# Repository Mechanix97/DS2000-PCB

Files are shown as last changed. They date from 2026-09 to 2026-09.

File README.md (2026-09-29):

<p align="center">
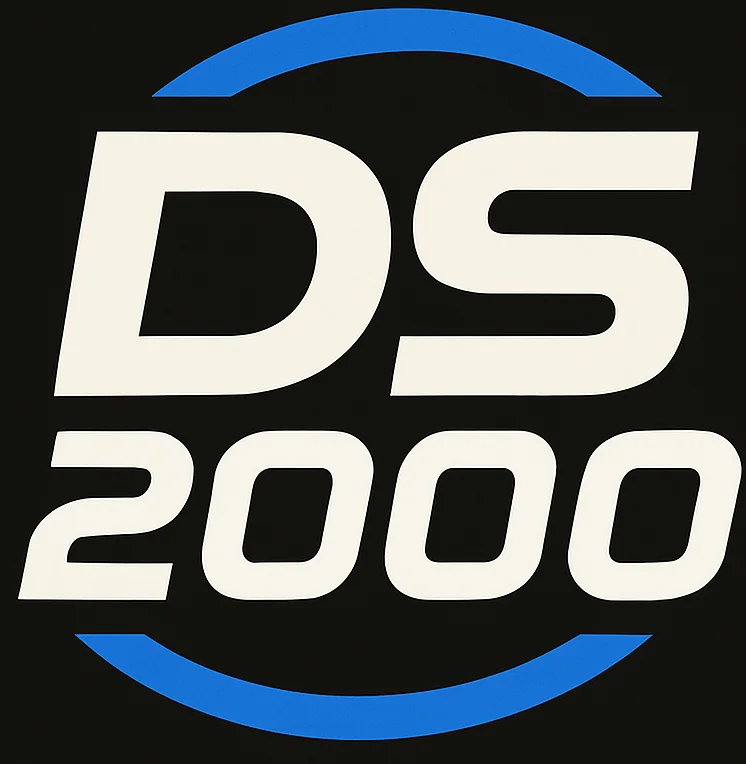
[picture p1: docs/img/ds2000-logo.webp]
DS2000
  
</p>

<p align="center">
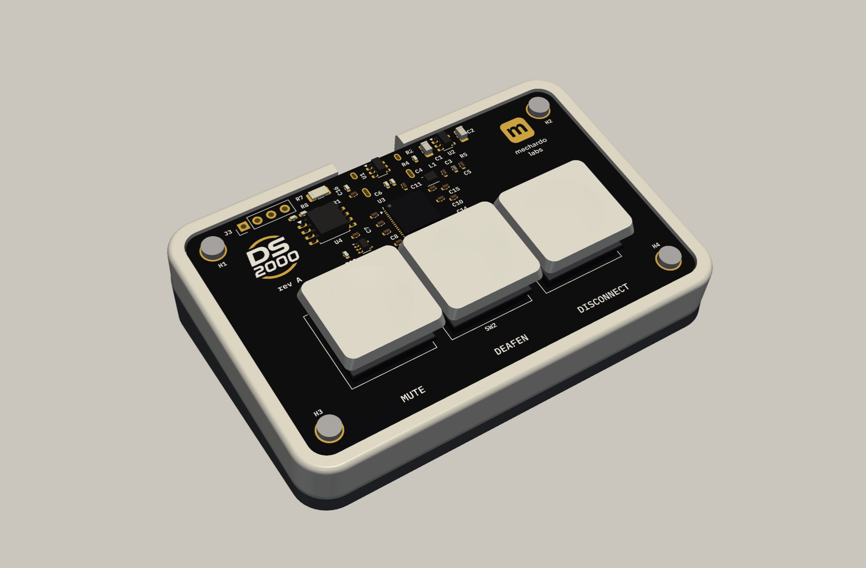
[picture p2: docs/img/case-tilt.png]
DS2000 rev A in its enclosure
  
</p>

<h1 align="center">DS2000 PCB</h1>

<p align="center">
  <b>Three keys for Discord: mute, deafen, disconnect.</b><br>
  RP2350A · Kailh Choc V1 · reverse-mounted RGB · USB-C · the board <i>is</i> the top face
</p>

KiCad design for the DS2000, a three-key Discord control deck. Mute and deafen are lit from
underneath by an RGB LED; disconnect has none. The board is also the device's visible top face: the
RP2350A, the logos and the legends are meant to be seen. It sits in a 3D-printed tray
([DS2000-Enclosure](https://github.com/Mechanix97/DS2000-Enclosure)).

| | |
|---|---|
| MCU | Raspberry Pi RP2350A |
| Keys | 3× Kailh Choc V1 (low profile) in a row, 18 mm pitch, soldered, MBK-style caps |
| LEDs | 2× SK6812MINI-E, reverse-mounted under the mute and deafen keys |
| Connector | USB-C (USB 2.0 full speed), or a cable soldered to J3 |
| Board | 4 layers, 1.6 mm, 72 × 46 mm, black mask, ENIG. RP2350A on show on top; USB-C, LEDs and debug pads underneath |
| Tool | **KiCad 10** |

Design decisions, block descriptions, BOM and open items: [`docs/design-rev-a.md`](docs/design-rev-a.md).

## In its enclosure

The same frame-style tray works flat on the desk or on a separate 7° wedge, held by magnets. The
board screws into it through its four corner holes.

<table>
  <tr>
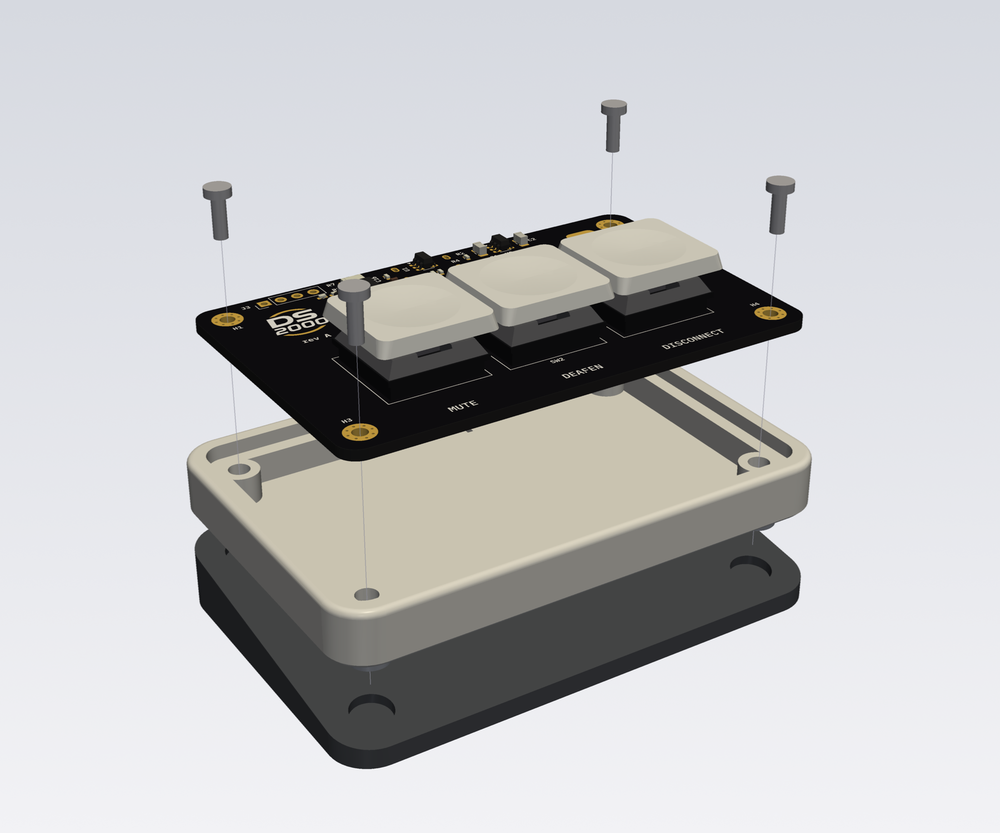
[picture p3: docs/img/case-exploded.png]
Exploded view: screws, board, tray, wedge
    <td width="50%"></td>
    <td width="50%">
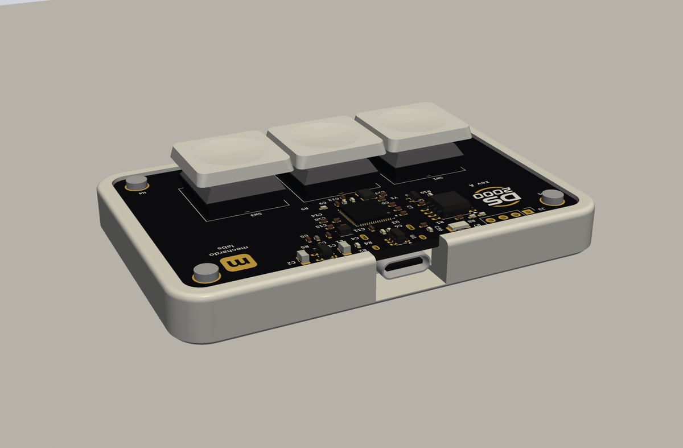
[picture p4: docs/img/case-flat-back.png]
Flat, from the back: USB-C through the frame
      <br>
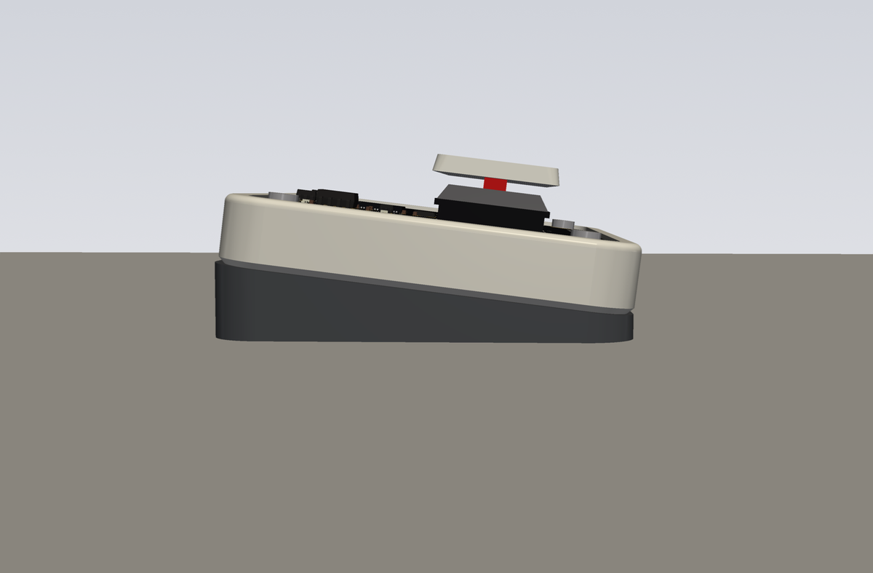
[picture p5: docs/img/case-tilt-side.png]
On the 7 degree wedge, from the side
      
    </td>
  </tr>
  <tr>
    <td>Exploded: four M2 screws, the board, the tray and the 7° wedge</td>
    <td>Flat, with the USB-C leaving straight back; and on the wedge, from the side</td>
  </tr>
</table>

## The board

| Top face, without switches | Underneath |
|---|---|
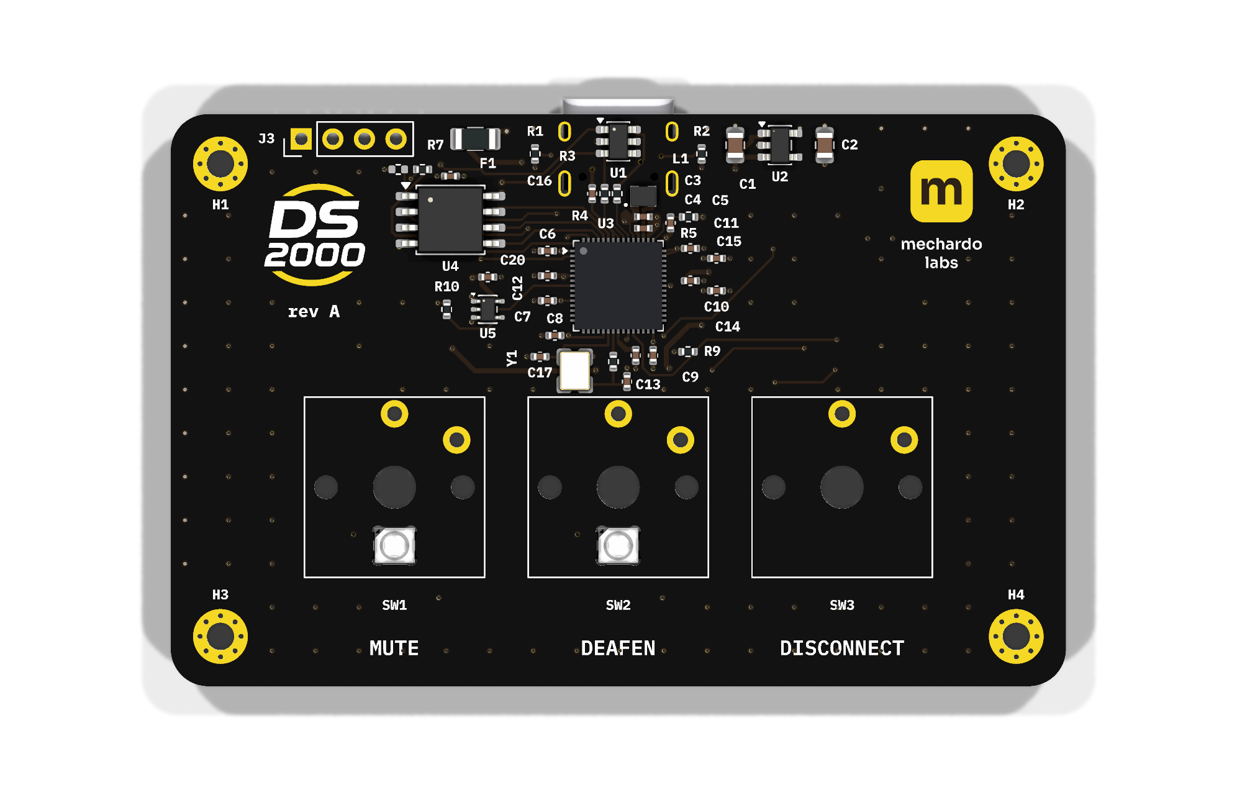
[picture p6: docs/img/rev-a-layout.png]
Top, without switches
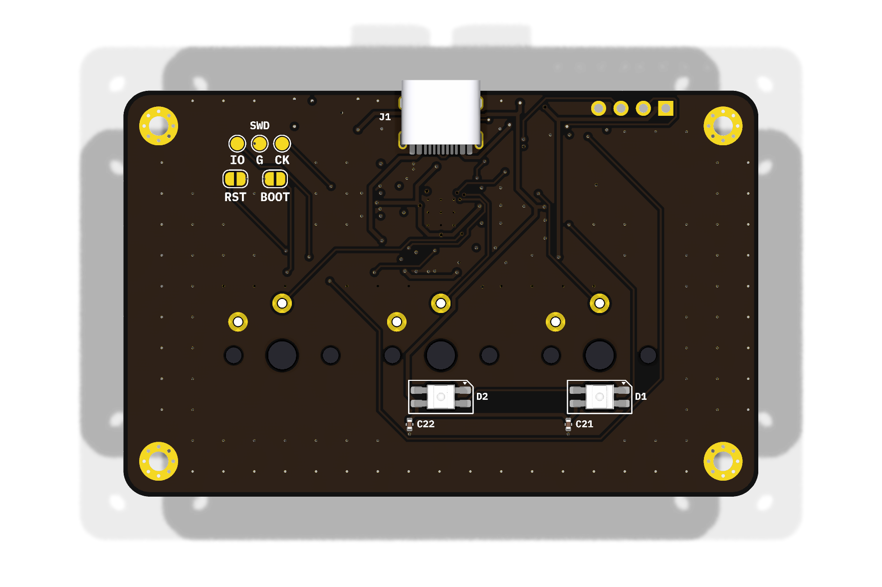
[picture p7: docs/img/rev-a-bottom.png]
Bottom
|  |  |
| The visible face: RP2350A, logos and legends | USB-C at the back edge, the two LEDs, debug pads (SWD, BOOT, RST) |

### Close up

| | |
|---|---|
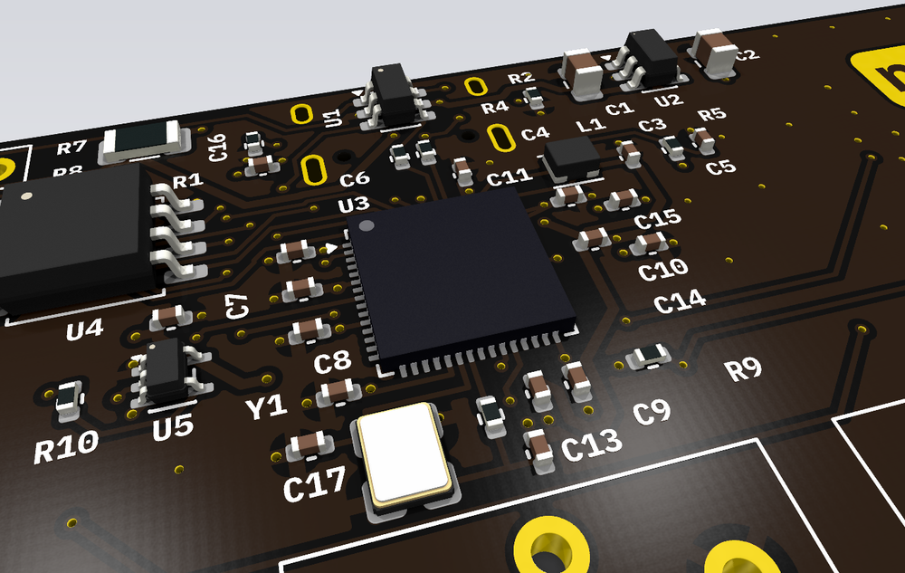
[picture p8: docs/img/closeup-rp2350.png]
RP2350A and its support parts
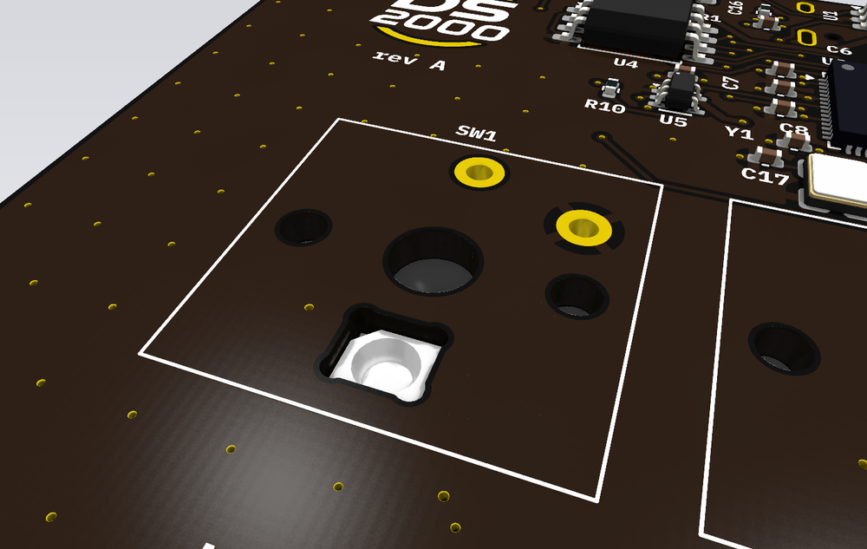
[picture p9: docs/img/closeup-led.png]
LED under the Choc switch
|  |  |
| **RP2350A on show**, with the flash, the 12 MHz crystal and the core regulator around it | **Light through the switch**: the SK6812MINI-E is mounted from below and shines through the Choc's LED window |
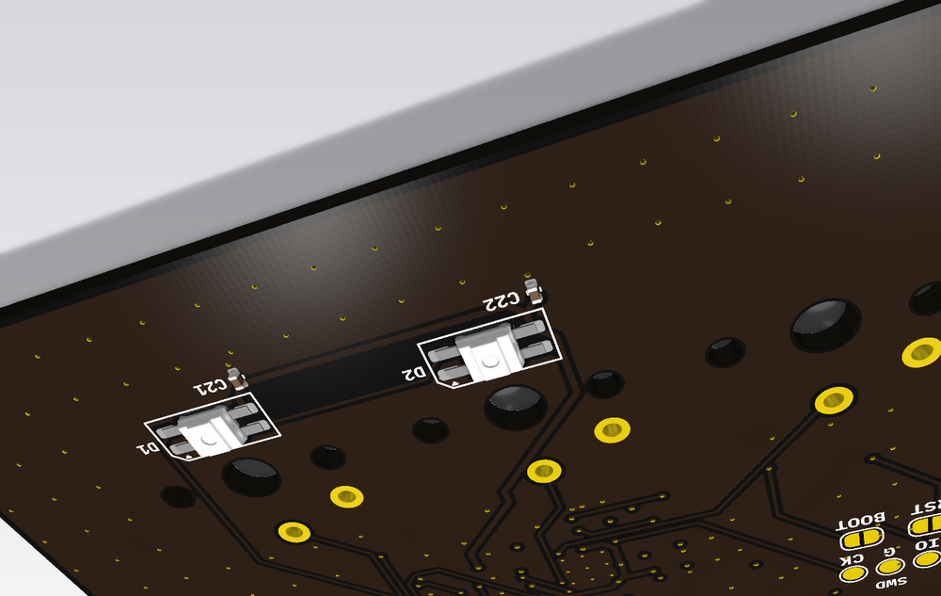
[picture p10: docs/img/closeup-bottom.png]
LEDs from below
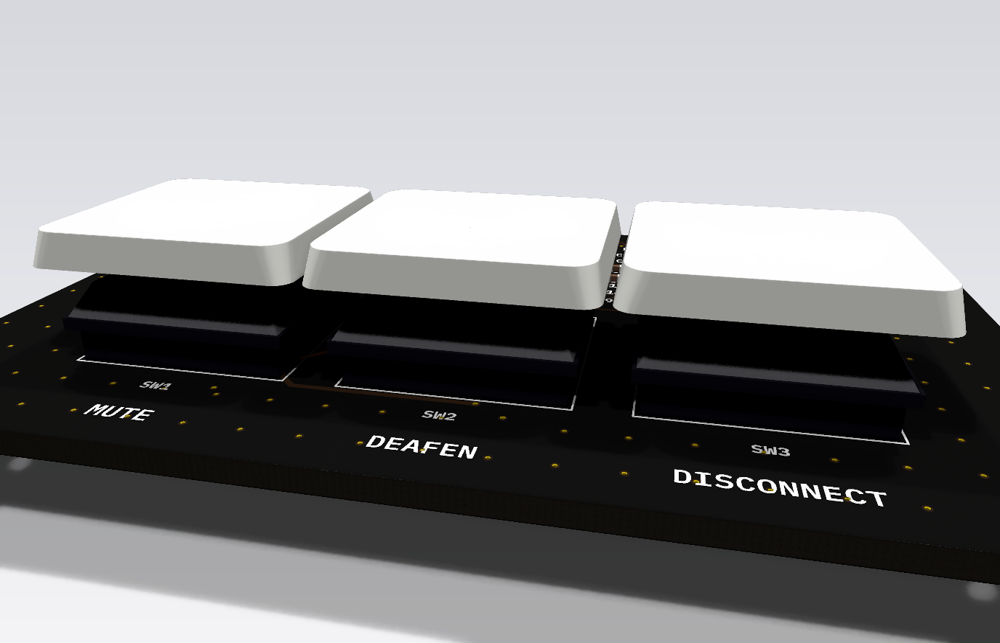
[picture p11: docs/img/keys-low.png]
Low-profile keys
|  |  |
| **Underneath**: both LEDs in a chain, each with its own 100 nF, and the debug pads | **Low profile**: Choc V1 with flat caps, keycap tops ~8.7 mm above the board |

<details>
<summary>More views</summary>

| With switches and keycaps | From the back |
|---|---|
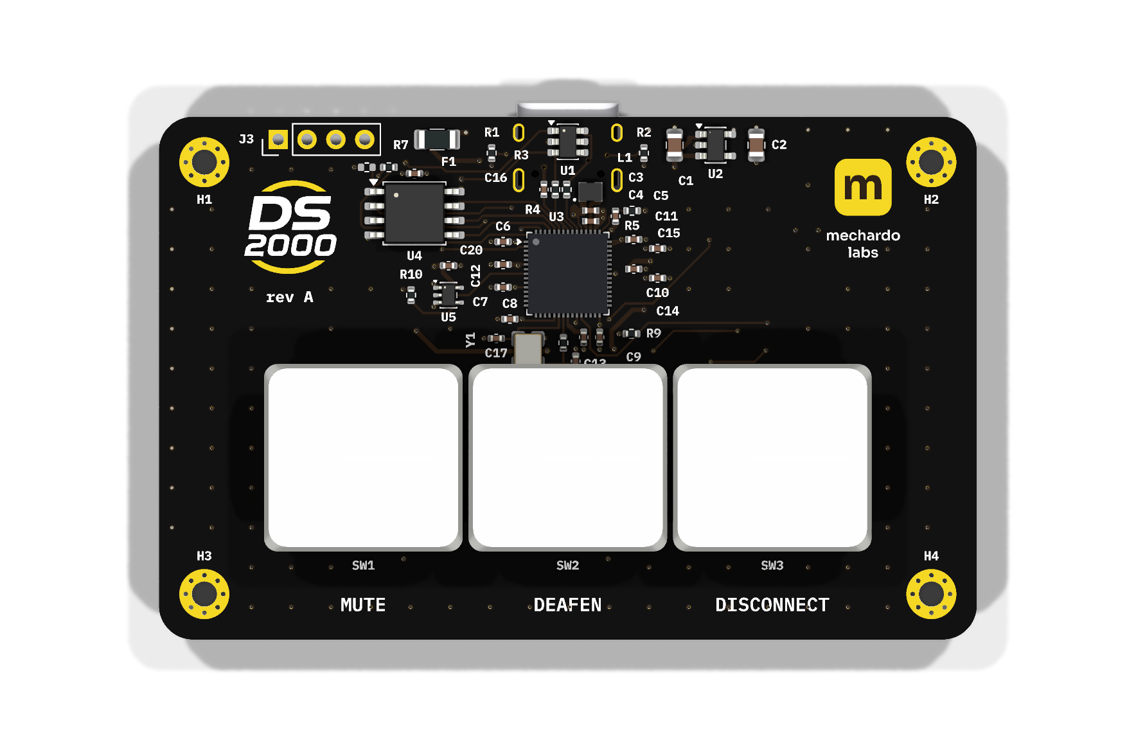
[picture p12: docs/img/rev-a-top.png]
Top
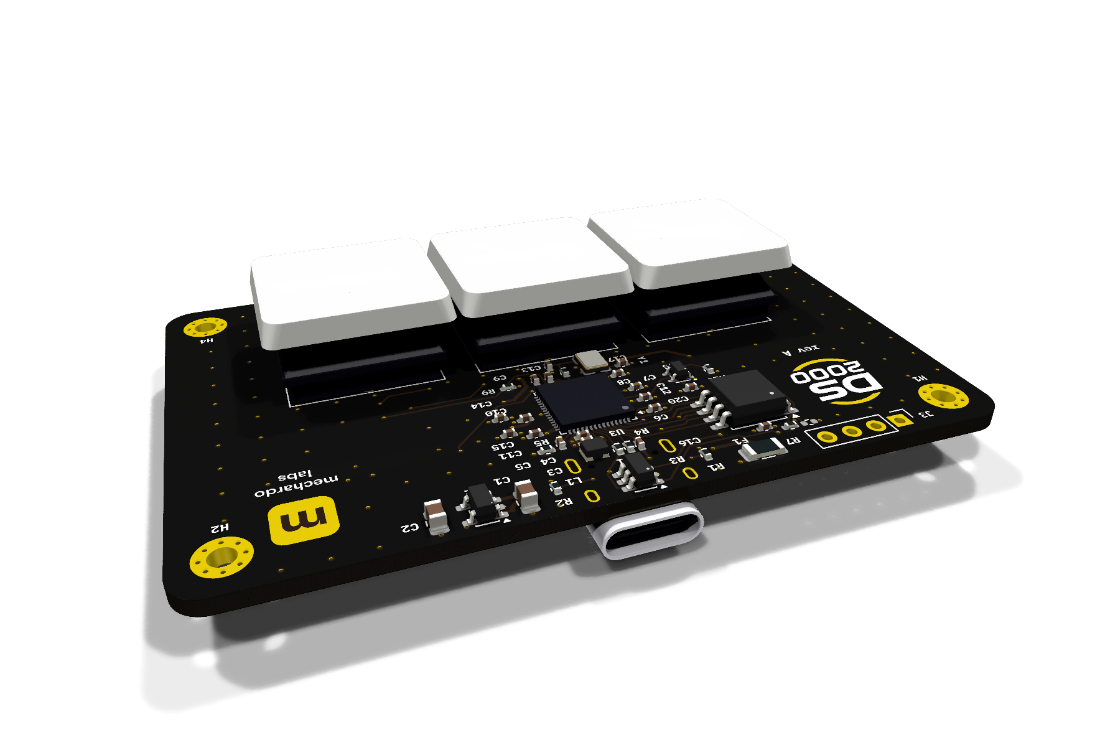
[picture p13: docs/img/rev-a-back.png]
Back
|  |  |

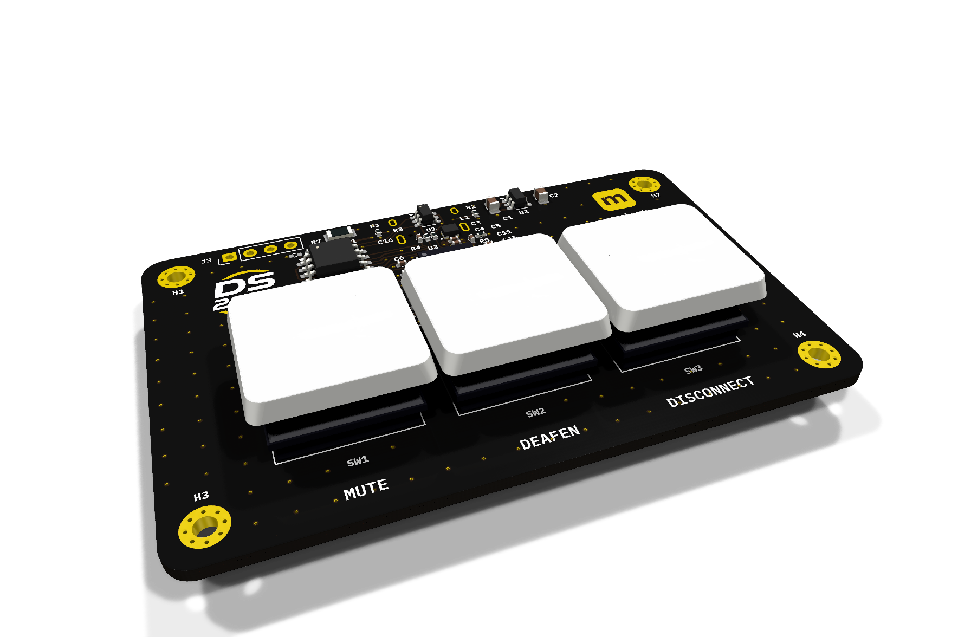
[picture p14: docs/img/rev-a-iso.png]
Isometric

</details>

### Schematic

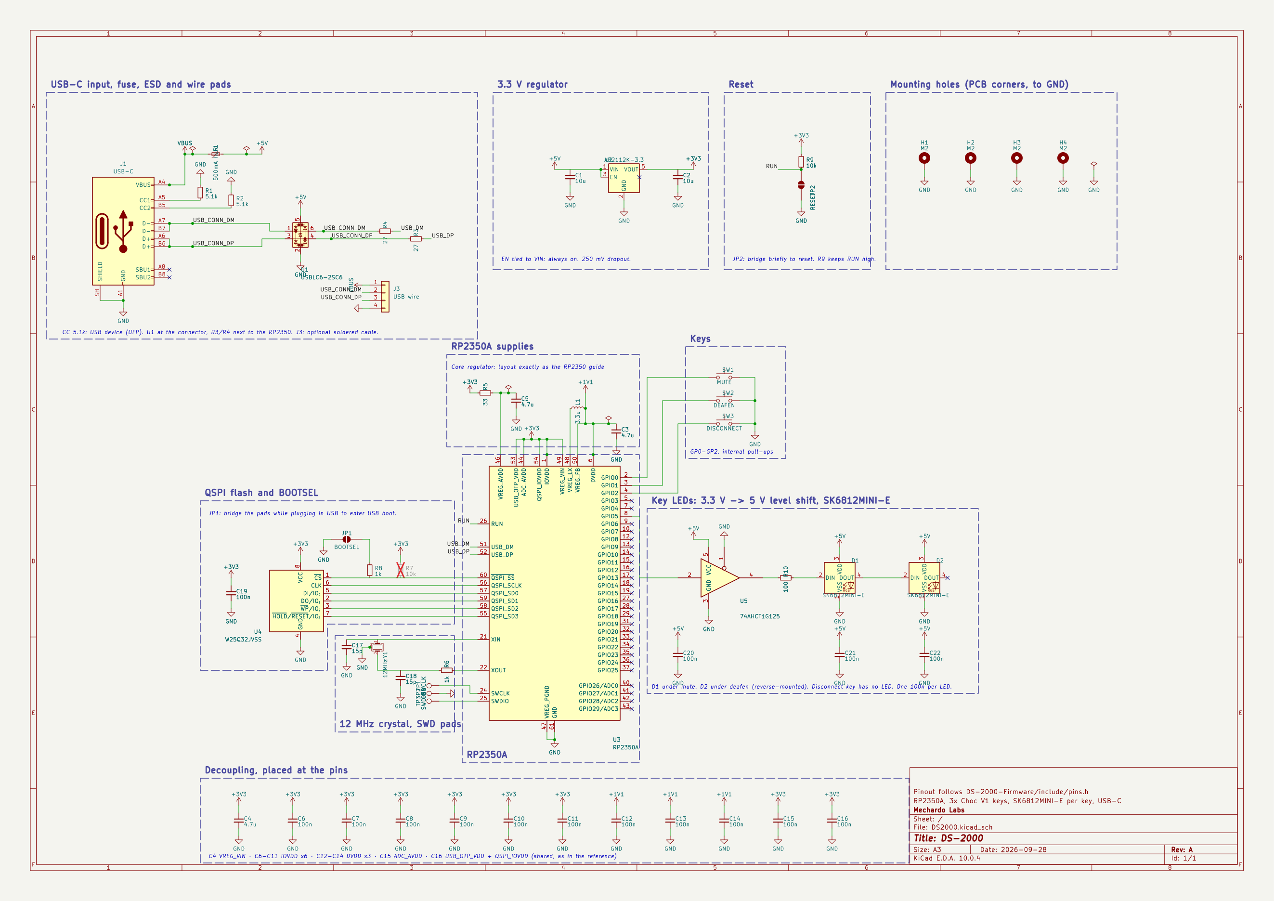
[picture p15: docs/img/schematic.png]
Schematic


One sheet, one box per block: USB-C input, 3.3 V regulator, RP2350A supplies, QSPI flash, crystal
and SWD, keys, and the LED chain with its 5 V level shifter.

## Pinout

The pinout is defined by the firmware (`DS2000-Firmware/include/pins.h`). Change it there first.

| Function | GPIO |
|---|---|
| Mute key | GP0 |
| Deafen key | GP1 |
| Disconnect key | GP2 |
| LED data (SK6812 chain, via 5 V level shifter) | GP5 |

## Checks

```sh
kicad-cli sch erc --severity-all DS2000.kicad_sch
kicad-cli sch export netlist --format kicadsexpr -o /tmp/ds2000.net DS2000.kicad_sch
```

CI (KiBot) runs ERC and DRC with schematic parity on every change and fails on any new error.

## Manufacturing

Every change also builds the files to order the board from JLCPCB, with assembly (artifact
`kibot-out` of the KiBot workflow):

- `JLCPCB/`: gerbers and drill (zipped), BOM with LCSC numbers, placement (CPL) with JLC's rotation fixes
- `step/`: the populated board as STEP, origin at its centre, for the [enclosure](https://github.com/Mechanix97/DS2000-Enclosure)

Board options, parts and what to check before ordering: [`docs/design-rev-a.md`](docs/design-rev-a.md#bill-of-materials).

## Related repositories

- [DS2000](https://github.com/Mechanix97/DS2000): desktop application
- [DS2000-Firmware](https://github.com/Mechanix97/DS2000-Firmware): firmware
- [DS2000-Enclosure](https://github.com/Mechanix97/DS2000-Enclosure): enclosure (Fusion 360)

## License

AGPL-3.0, see [`LICENSE`](LICENSE). Whether the hardware should move to CERN-OHL-S is discussed
in #16.

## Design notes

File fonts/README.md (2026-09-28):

# Fonts

The board's silkscreen uses the typography of [mechardo3d.xyz](https://mechardo3d.xyz):

| Face | Used for |
|---|---|
| Sora Bold | "DS2000" |
| Sora SemiBold | "mechardo labs" |
| IBM Plex Mono SemiBold | key legends |
| IBM Plex Mono Bold | references, debug labels, "rev A" |

`DS2000.kicad_pcb` embeds them, so KiCad renders the board correctly without installing anything.
To **edit** those texts, install the files in this folder first.

`SoraSemiBold-Regular.ttf` is a static instance of the variable Sora font at weight 600, renamed to
the family "Sora SemiBold" so KiCad can pick it by name.

Both families are under the SIL Open Font License 1.1 (`OFL-*.txt`).

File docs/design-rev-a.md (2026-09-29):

# DS2000 rev A — design notes

Rev A replaces the 2025 RP2040 draft (last seen at commit `7db9552`). It was drawn from scratch,
using the draft only as a reference, and fixes every defect found in it (DS2000-PCB#2-#10).

## Product decisions

| Decision | Choice | Why |
|---|---|---|
| MCU | Discrete **RP2350A** (QFN-60) | Same family as the RP2350-Zero test module the firmware runs on |
| Look | **Exposed PCB as the top face**, enclosure is a tray underneath | The board is the product's face: logo, art, legends in silkscreen |
| Top side | Switches, and **the RP2350A and its circuitry on show** in a strip behind the keys | The visible chip is part of the look |
| Bottom side | The two reverse-mount LEDs, the **USB-C receptacle** and **all debug pads** (SWD, BOOT, RST) | The plug and cable sit low, level with the tray, the top strip gains space, and debug stays off the visible face. Assembly is two-sided |
| Layers | 4 (Sig / GND / PWR / Sig), 1.6 mm | Routes mostly on inner layers so the face stays clean, solid reference for USB and the core regulator, stiff enough to hold switches without a plate |
| Finish (proposed) | Matte black soldermask, ENIG | Gold for exposed logo copper and mounting rings |
| Keys | 3× Kailh Choc V1 (low profile), **soldered, no plate**, in a row, MBK-style keycaps | Changed from Cherry MX for a lower, flatter device. Choc V1 has two locating posts, so it sits steady without a plate |
| Size | 72 × 46 mm | 3 keys at the Choc 18 mm pitch plus corner M2 holes; the extra depth is the component strip behind the keys. Kept from the MX layout so the enclosure's numbers stay put |
| Status | **SK6812MINI-E** reverse-mount under the mute and deafen keys; **disconnect has no LED** | Lights the key through the switch LED window; needs shine-through or translucent keycaps |
| Pinout | Owned by `DS2000-Firmware/include/pins.h` | See below |

## Blocks

**USB-C and power.** HRO TYPE-C-31-M-12 on the **bottom** side at the back edge, pointing backwards, so the plug and cable sit low and the top strip stays free. The tray needs a pocket of at least 4 mm under the board and a cut-out in its back wall for the plug overmould (about 12.5 × 6.5 mm). J3 is four bare 2.54 mm holes (VBUS, D-, D+, GND) to solder a USB cable instead of fitting J1; it sits upstream of the fuse and ESD, so a soldered cable is protected the same way. 5.1 kΩ on CC1/CC2
(UFP). VBUS goes through F1 (500 mA hold PTC) to `+5V`, which feeds the LEDs and the level shifter.
USBLC6-2SC6 ESD on D+/D- close to the connector. AP2112K-3.3 LDO (250 mV dropout, 600 mA) makes
`+3V3`; the RP2350 minimal design uses an NCP1117, but its ~1.1 V dropout leaves little margin from
a 4.75 V VBUS after the fuse.

**RP2350A.** Straight from *Hardware design with RP2350* (Minimal design, R4):

- Core supply from the on-chip switching regulator: `VREG_LX` → L1 3.3 µH → `+1V1` (DVDD ×3 and
  `VREG_FB`), C3 4.7 µF output, C4 4.7 µF on `VREG_VIN`, `VREG_AVDD` through R5 33 Ω / C5 4.7 µF.
  **L1 must be the polarity-marked Abracon AOTA-B201610S3R3-101-T, placed in the orientation and
  layout the guide shows.** Raspberry Pi explicitly says other layouts are at your own risk.
- `VREG_PGND` to GND, routed as the guide describes (not to an arbitrary via).
- **Layout: a copy of Raspberry Pi's RPI-RP2350A-MINIMAL R4-S1 board** (KiCad files, MIT), see
  *Core regulator* under Layout.
- 100 nF per power pin: C6-C11 IOVDD, C12-C14 DVDD, C15 ADC_AVDD, C16 shared by USB_OTP_VDD and
  QSPI_IOVDD (as in the reference).
- Crystal ABM8-272-T3 12 MHz, 15 pF load caps, 1 kΩ on XOUT. Do not substitute.
- USB 27 Ω series resistors R3/R4 close to the chip; D+/D- as a 90 Ω differential pair over
  unbroken GND.
- Flash W25Q32JVSSIQ (4 MB, same size as the RP2350-Zero, so the firmware image is identical).
  R7 (10 kΩ CS pull-up) is DNP as in the reference.
- BOOTSEL: no button. JP1 is a pair of bare pads (open solder jumper) that pull `QSPI_SS` low through
  R8 1 kΩ when bridged with tweezers or a wire while USB is plugged in (or RESET pressed).
  RESET: likewise pads, JP2, from `RUN` to GND; R9 10 kΩ keeps `RUN` high. Firmware updates do not
  need either: the running firmware reboots itself into USB boot (DS2000-Firmware#14, #15; DS2000#35).
- SWD on three bare pads on the bottom, TP1-TP3 (SWCLK, GND, SWDIO, the Debug Probe order); no connector.

**Keys and LEDs.** SW1-SW3 to GPIO0-2 and GND; the firmware uses the internal pull-ups (not
affected by the RP2350-E9 erratum, which concerns pull-downs). The LED data line leaves GPIO5 at
3.3 V and is shifted to 5 V by U5 (74AHCT1G125, TTL-level input), then R10 100 Ω, then the chain
D1 (mute) → D2 (deafen); D2's DOUT is unused. Each LED has its own 100 nF. SK6812 data input needs
0.7 × VDD = 3.5 V at 5 V, which a 3.3 V GPIO does not guarantee; hence the shifter.

## Pinout

| Function | GPIO | Net |
|---|---|---|
| Mute key | GP0 | `KEY_MUTE` |
| Deafen key | GP1 | `KEY_DEAFEN` |
| Disconnect key | GP2 | `KEY_DISCONNECT` |
| LED data (to U5) | GP5 | `LED_DIN_3V3` |

**Firmware impact** (tracked in Mechanix97/DS2000-Firmware#13): the six PWM LED pins (GP5-GP10) are gone. The firmware needs a
WS2812/SK6812 driver on GP5 (arduino-pico ships `Adafruit_NeoPixel`-compatible PIO drivers), and
`pins.h` changes accordingly. The serial protocol does not change: it already carries a colour for
each of the two status LEDs, which map one-to-one onto D1 and D2.

## Bill of materials

The MPN, manufacturer and LCSC number of every assembled part live in the schematic's fields, written
by `tools/bom/set_fields.py` (the parts table is there, with where each number was checked). The same
script copies them onto the board's footprints so the schematic parity check stays clean. Change a
part there and re-run it.

| Refs | Value | MPN | LCSC | Footprint |
|---|---|---|---|---|
| U3 | RP2350A | RP2350A | C42411118 | QFN-60 7×7 mm, thermal vias |
| U4 | Flash 4 MB | W25Q32JVSSIQ | C179173 | SOIC-8 5.3 mm |
| Y1 | 12 MHz | ABM8-272-T3 | C20625731 | 3225 4-pin |
| L1 | 3.3 µH | AOTA-B201610S3R3-101-T | C42411119 | 2016, polarity dot on pad 1 = +1V1 |
| U2 | 3.3 V LDO | AP2112K-3.3TRG1 | C51118 | SOT-23-5 |
| U1 | USB ESD | USBLC6-2SC6 | C7519 | SOT-23-6 |
| U5 | Buffer, TTL in | 74AHCT1G125GW,125 | C12495 | SOT-353 |
| D1, D2 | RGB LED | SK6812MINI-E | C5149201 | reverse mount 3.2×2.8, **bottom** |
| J1 | USB-C 16P | HRO TYPE-C-31-M-12 | C165948 | **bottom** |
| F1 | PTC 500 mA hold, 15 V | Littelfuse 1206L050/15YR | C151162 | 1206 (the 6 V 1206L050YR leaves little margin on VBUS) |
| C1, C2 | 10 µF 25 V X5R | CL21A106KAYNNNE | C15850 | 0805 |
| C3-C5 | 4.7 µF X5R | GRM155R60J475ME47D | C82453 | 0402 (C3/C4 wide land), as the RP2350 reference |
| C6-C16, C19-C22 | 100 nF 16 V X7R | CL05B104KO5NNNC | C1525 | 0402 (C21/C22 bottom) |
| C17, C18 | 15 pF C0G | 0402CG150J500NT | C1548 | 0402 |
| R1, R2 | 5.1 kΩ 1 % | 0402WGF5101TCE | C25905 | 0402 |
| R3, R4 | 27 Ω 1 % | RC0402FR-0727RL | C138021 | 0402, as the reference |
| R5 | 33 Ω 1 % | RC0402FR-0733RL | C138002 | 0402, as the reference |
| R6, R8 | 1 kΩ 1 % | 0402WGF1001TCE | C11702 | 0402 |
| R7 | 10 kΩ, **DNP** | 0402WGF1002TCE | C25744 | 0402 |
| R9 | 10 kΩ 1 % | 0402WGF1002TCE | C25744 | 0402 |
| R10 | 100 Ω 1 % | 0402WGF1000TCE | C25076 | 0402 |
| SW1-SW3 | Keys | Kailh Choc V1 (CPG1350) | — | soldered by hand |
| TP1-TP3, JP1, JP2, J3, H1-H4 | pads, jumpers, wire holes, M2 holes | — | — | bare copper |

**Ordering from JLCPCB.** CI builds the files on every change (KiBot's JLCPCB template, artifact
`kibot-out`, folder `JLCPCB/`): gerbers and drill zipped, the BOM and the placement (CPL) file with
JLC's rotation corrections. Upload the zip as the PCB, then the BOM and CPL for assembly:

- 4 layers, 1.6 mm, **black** mask, white silk, **ENIG**, JLC04161H-7628 stackup
- assembly on **both sides**: D1, D2, C21, C22 and J1 are on the bottom
- JLC's BOM page shows which lines are basic or extended parts (extended ones add a setup fee each)
- check the placement preview, above all the rotation of U3, U5, D1/D2 and J1, before confirming
- the switches are fitted by hand after assembly

## Layout

rev A, routed

**State:** placed and fully routed. ERC is clean; DRC reports no unconnected pads, no clearance or
edge errors and full schematic parity (Update PCB from Schematic reports no changes). The only DRC
item left is the intended USB-C footprint change described under *Face and branding*.

**Fixed (mechanical, agreed with the enclosure):**

| Item | Position |
|---|---|
| Outline | 72 × 46 mm, 3 mm corner radius |
| Keys | row of 3 at 18 mm pitch, centres 16 mm from the front edge, middle key on the board's centre line |
| LEDs | D1/D2 on the bottom, 4.7 mm south of the switch centre (the Choc V1 LED window, opposite the switch pins), turned so DOUT faces the next LED |
| Holes | 4 × M2, 4 mm in from each edge, clear of the keycaps |
| USB-C | bottom side, centred on the back edge, face **1.2 mm past the edge** (its front shield tabs keep 0.6 mm of board), opening facing back |
| Debug | **all on the bottom**, back right: SWD pads TP1-TP3 (CK, G, IO), BOOT (JP1), RST (JP2) |
| USB wire holes (J3) | back edge, left |

**Top side, around the RP2350A:** flash top-left by the QSPI pins, core regulator straight above the
VREG pins, USB series resistors beside it above D+/D-, crystal below XIN/XOUT, each decoupling
capacitor in line with its supply pin and its supply pad facing it.

**Core regulator.** Raspberry Pi says their regulator layout should be copied, not improvised: the
inductor's field upsets the output capacitor when it is the wrong way round or placed differently.
Rev A copies it from their KiCad files (RPI-RP2350A-MINIMAL R4-S1, MIT). Our U3 sits the same way
round as theirs, so every offset from VREG_LX (pin 48) carries over unchanged:

| Theirs | Ours | Part | From pin 48 (x, y), mm |
|---|---|---|---|
| C6 | C4 | 4.7 µF, VREG_VIN | (0, −1.16) |
| C7 | C3 | 4.7 µF, +1V1 output | (0, −2.10) |
| L1 | L1 | AOTA-B201610S3R3-101-T, dot (pad 1) on +1V1, left | (0, −3.75) |
| C9 | C5 | 4.7 µF, VREG_AVDD | (2.2, −1.60) |
| R3 | R5 | 33 Ω, VREG_AVDD filter | (3.65, −2.08) *(theirs: (2.2, −3.45))* |
| C12 | C16 | 100 nF, USB_OTP_VDD + QSPI_IOVDD | (−4.1, −3.95) |
| R7/R8 | R3/R4 | 27 Ω, USB | (−3.1 / −2.1, −3.95) |

- The two 4.7 µF caps use the reference's wide 0402 land (`DS2000:C_0402_1005Metric_Wide`, pads
  1.03 mm apart) so VREG_LX runs straight up between them to L1.
- VREG_PGND (47) ties to both caps' ground pads on the top layer, with two vias beside them, as in
  the reference; VREG_FB (50) is taken at the output cap; VREG_AVDD runs clear of L1.
- The tracks are hand-placed by `preroute.py` and locked; `vreg_pours.py` adds the reference's four
  small pours (PGND, VREG_LX, the +1V1 node, VREG_VIN) after autorouting.
- The reference's +3V3 pour under the package (joining VREG_VIN to pins 53/54) becomes a track in the
  same place, between the pin ring and the exposed pad, with one via to the In2 plane.
- **Two departures**, both forced by J1 underneath: the whole RP2350A cluster sits 0.5 mm lower than
  first placed so L1 and C16 clear J1's plastic pegs, and R5 lies beside C5 instead of above it,
  where J1's shell pin comes through. R5 only feeds the 200 µA AVDD filter, away from L1's field.
- No via lands on J1's bottom-side contacts: every via on the board is at least 0.4 mm clear of them.

**Face and branding** (`tools/pcb-generator/branding.py`, safe to re-run on the hand-edited board):

- F.Cu carries a GND pour as well, so all four layers are ground or +3V3 wherever there is no track.
  Its thermal reliefs may resolve to a single spoke (`DS2000.kicad_dru`): every top GND pad already
  reaches In1 through its own via.
- Every reference designator is visible, placed by a script at the first spot beside its part that
  clears pads, holes, vias, other text and the board edge. The three that find no room (C6, C11, R3,
  in the tightest spot around the RP2350A) stay hidden; they are still in the assembly drawings.
- Typography follows mechardo3d.xyz: Sora for "DS2000" and "mechardo labs", IBM Plex Mono for the
  key legends, references and debug labels. The fonts are embedded in the board file; `fonts/` has
  them for editing. KiCad reports `text_thickness` on some characters (5, 6, 9, G, a, e): its check
  measures the thinnest part of each glyph, where curves taper. The main strokes of Plex Mono Bold at
  0.8 mm are about 0.16 mm, above JLC's 0.153 mm minimum.
- The DS2000 logo (back left) is the product logo from mechardo3d.xyz
  (`static/images/DS2000/logo/ds2000-logo.webp`), traced by `tools/logo/gen_ds2000_logo.py` into
  `DS2000.pretty/Logo_DS2000_8.6mm`: the white lettering is silkscreen, the blue arcs become ENIG
  gold, since the board has no blue. "rev A" sits under it; the maker block (Mechardo mark with
  "mechardo / labs") sits back right.
- The Mechardo Labs mark is the mechardo3d.xyz favicon (`tools/logo/gen_logo.py` →
  `DS2000.pretty/Logo_Mechardo_5mm`): a rounded square of ENIG copper whose mask opening leaves the
  "m" covered, so it reads black on gold. The SVG's "m" is a single self-overlapping contour, so it is
  first resolved to its nonzero-fill union; taken as-is the overlaps rendered as holes.
- The USB-C's own silkscreen, which fell past the board edge, is on the fab layer; that is the one
  intended `lib_footprint_mismatch` in the DRC output.

**How it was routed** (`tools/pcb-generator/`, see `pipeline.py`):

1. `gen_pcb.py` builds the board from the schematic's netlist (footprints, nets, fields, symbol
   links), places it, and sets stackup, rules and net classes.
2. `preroute.py` hand-routes what the autorouter should not improvise, as locked tracks: the crystal
   loop (XIN 7.4 mm, XOUT 2.1 mm, crystal output 4.9 mm, no vias, the crystal turned so the two
   nets never cross) and IOVDD pin 20, which runs to its capacitor above the XIN run.
3. `fanout.py` connects every GND and +3V3 pad to its plane: RP2350A supply pins go by a short
   track straight to their decoupling capacitor, pins 53/54 share one via between the USB and QSPI
   escapes, and every other pad gets its own via, each checked for clearance before it is placed.
4. Freerouting routes the rest on F.Cu and B.Cu (In1 and In2 are planes). The top is the product's
   face, so `top_keepout.py` first puts a track keepout on F.Cu over everything but the component
   strip around the RP2350A (x 80.5-119, y 71-93.6): the keys, the logos and the sides stay free of
   tracks and every longer run (+5V to the LEDs, the debug lines, the keys) goes underneath. The
   keepout comes out again after routing. Incremental passes are kept only when KiCad's own DRC
   counts fewer unconnected items, and `cleanup_vias.py` drops any via left dangling.
5. `branding.py` finishes the face (see above) and `stitch.py` ties the F.Cu and B.Cu GND pours to
   In1 with a 3.5 mm grid of vias wherever they clear everything else (113 on rev A).

`pipeline.py` writes to `build/` and never overwrites the committed board: from now on the
`.kicad_pcb` is edited by hand in KiCad.

**3D models:** KiCad's library has no STEP for the Choc V1 switch, the HRO USB-C or the QFN-60, so
`tools/3d-models/gen_models.py` generates simplified ones from datasheet dimensions into
`3dmodels/DS2000.3dshapes/` (referenced through `${KIPRJMOD}`, so they travel with the project). The
switches also carry an MBK-style keycap model for previews and for fitting the enclosure. The Cherry MX
models stay in the generator for reference.

**Choc V1 footprint:** `DS2000.pretty/SW_Kailh_Choc_V1_1.00u`, written by `tools/footprints/gen_choc_v1.py`
from Kailh's CPG1350 datasheet; the geometry matches kiswitch's footprint of the same name (MIT). Its
courtyard follows the 13.8 mm lower housing: the 15 mm flange is 2.2 mm up, so the crystal and C18
tuck under its edge.

**Stackup and rules:** JLCPCB JLC04161H-7628, 4 layers, 1.6 mm, black mask, white silk, ENIG.
In1 is the GND plane, In2 the +3V3 plane, F.Cu and B.Cu GND pours (solid joins on B.Cu). Minimums set for
JLC: 0.1 mm track and clearance, 0.2 mm drill, 0.3 mm copper to edge (0.2 mm only for the LED
cut-outs, in `DS2000.kicad_dru`). Net classes: *Plane* (GND, +3V3) reached by vias, *Power* (+5V,
+1V1, VBUS, VREG_LX) 0.4 mm, *USB* 0.2 mm tracks / 0.2 mm gap.

**Review (2026-09-28).** Every net was checked against Raspberry Pi's RP2350 minimal design and
every footprint's pin mapping against its datasheet, including the SK6812MINI-E: its datasheet
numbers pins differently from KiCad's symbol, but KiCad's reverse-mount footprint is drawn mirrored,
so once placed on the bottom each pad lands on the right function. No wrong connection was found.
The review did find routing the autorouter had done poorly, since fixed: XIN was 14 mm with two
vias and the QSPI clock 35.5 mm with four (now 7.4 mm with none, and 11 mm with two). The USB data
lines carry a ~2 cm stub to the J3 wire holes, which is harmless at full speed (12 Mbit/s).

**Review before ordering:**

- Core regulator: copied from the reference (see above). At assembly, check L1's dot sits on the
  left, towards +1V1 (the silkscreen dot marks it).
- USB: confirm the 90 Ω pair geometry with JLC's impedance calculator for this stackup.
- Under the keycaps (outside each switch's 13.8 mm lower housing) parts are hidden but must stay under
  ~2 mm high: the switch flange is 2.2 mm up and a pressed Choc keycap comes down close to it.
- Confirm the LED side against your switches: the footprint assumes the LED window is on the side
  opposite the two switch pins, as in Kailh's CPG1350 drawing.

## Open items

- [ ] Review the routed board (see Layout, *Review before ordering*)
- [ ] Mute and deafen keycaps must be shine-through or translucent for their LEDs to be visible

## Regenerating the schematic

`tools/schematic-generator/gen_sch.py` produced the first version of `DS2000.kicad_sch`: one titled
box per stage, wired inside each stage, net labels only between stages. `check_netlist.py` compares
KiCad's netlist export with the connectivity declared in the generator; both it and ERC (0
violations) passed. From here on,
**the `.kicad_sch` is the source of truth**: edit it in KiCad. The generator is kept only as a
record of how the first version was derived.

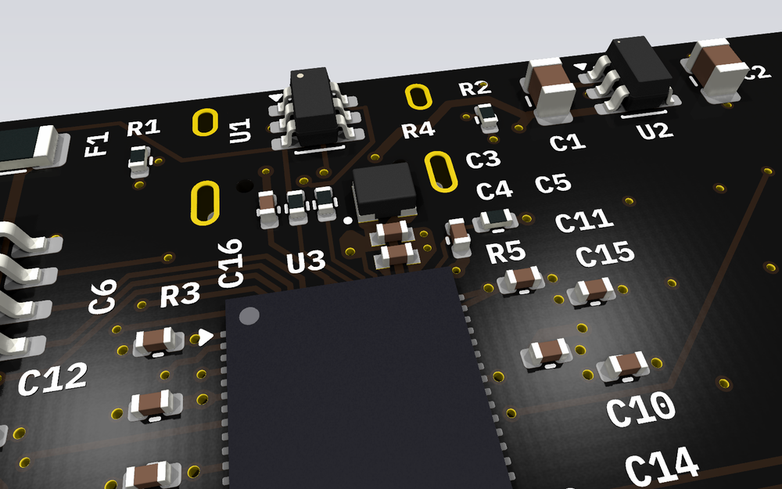
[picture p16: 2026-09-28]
docs/img/closeup-vreg.png

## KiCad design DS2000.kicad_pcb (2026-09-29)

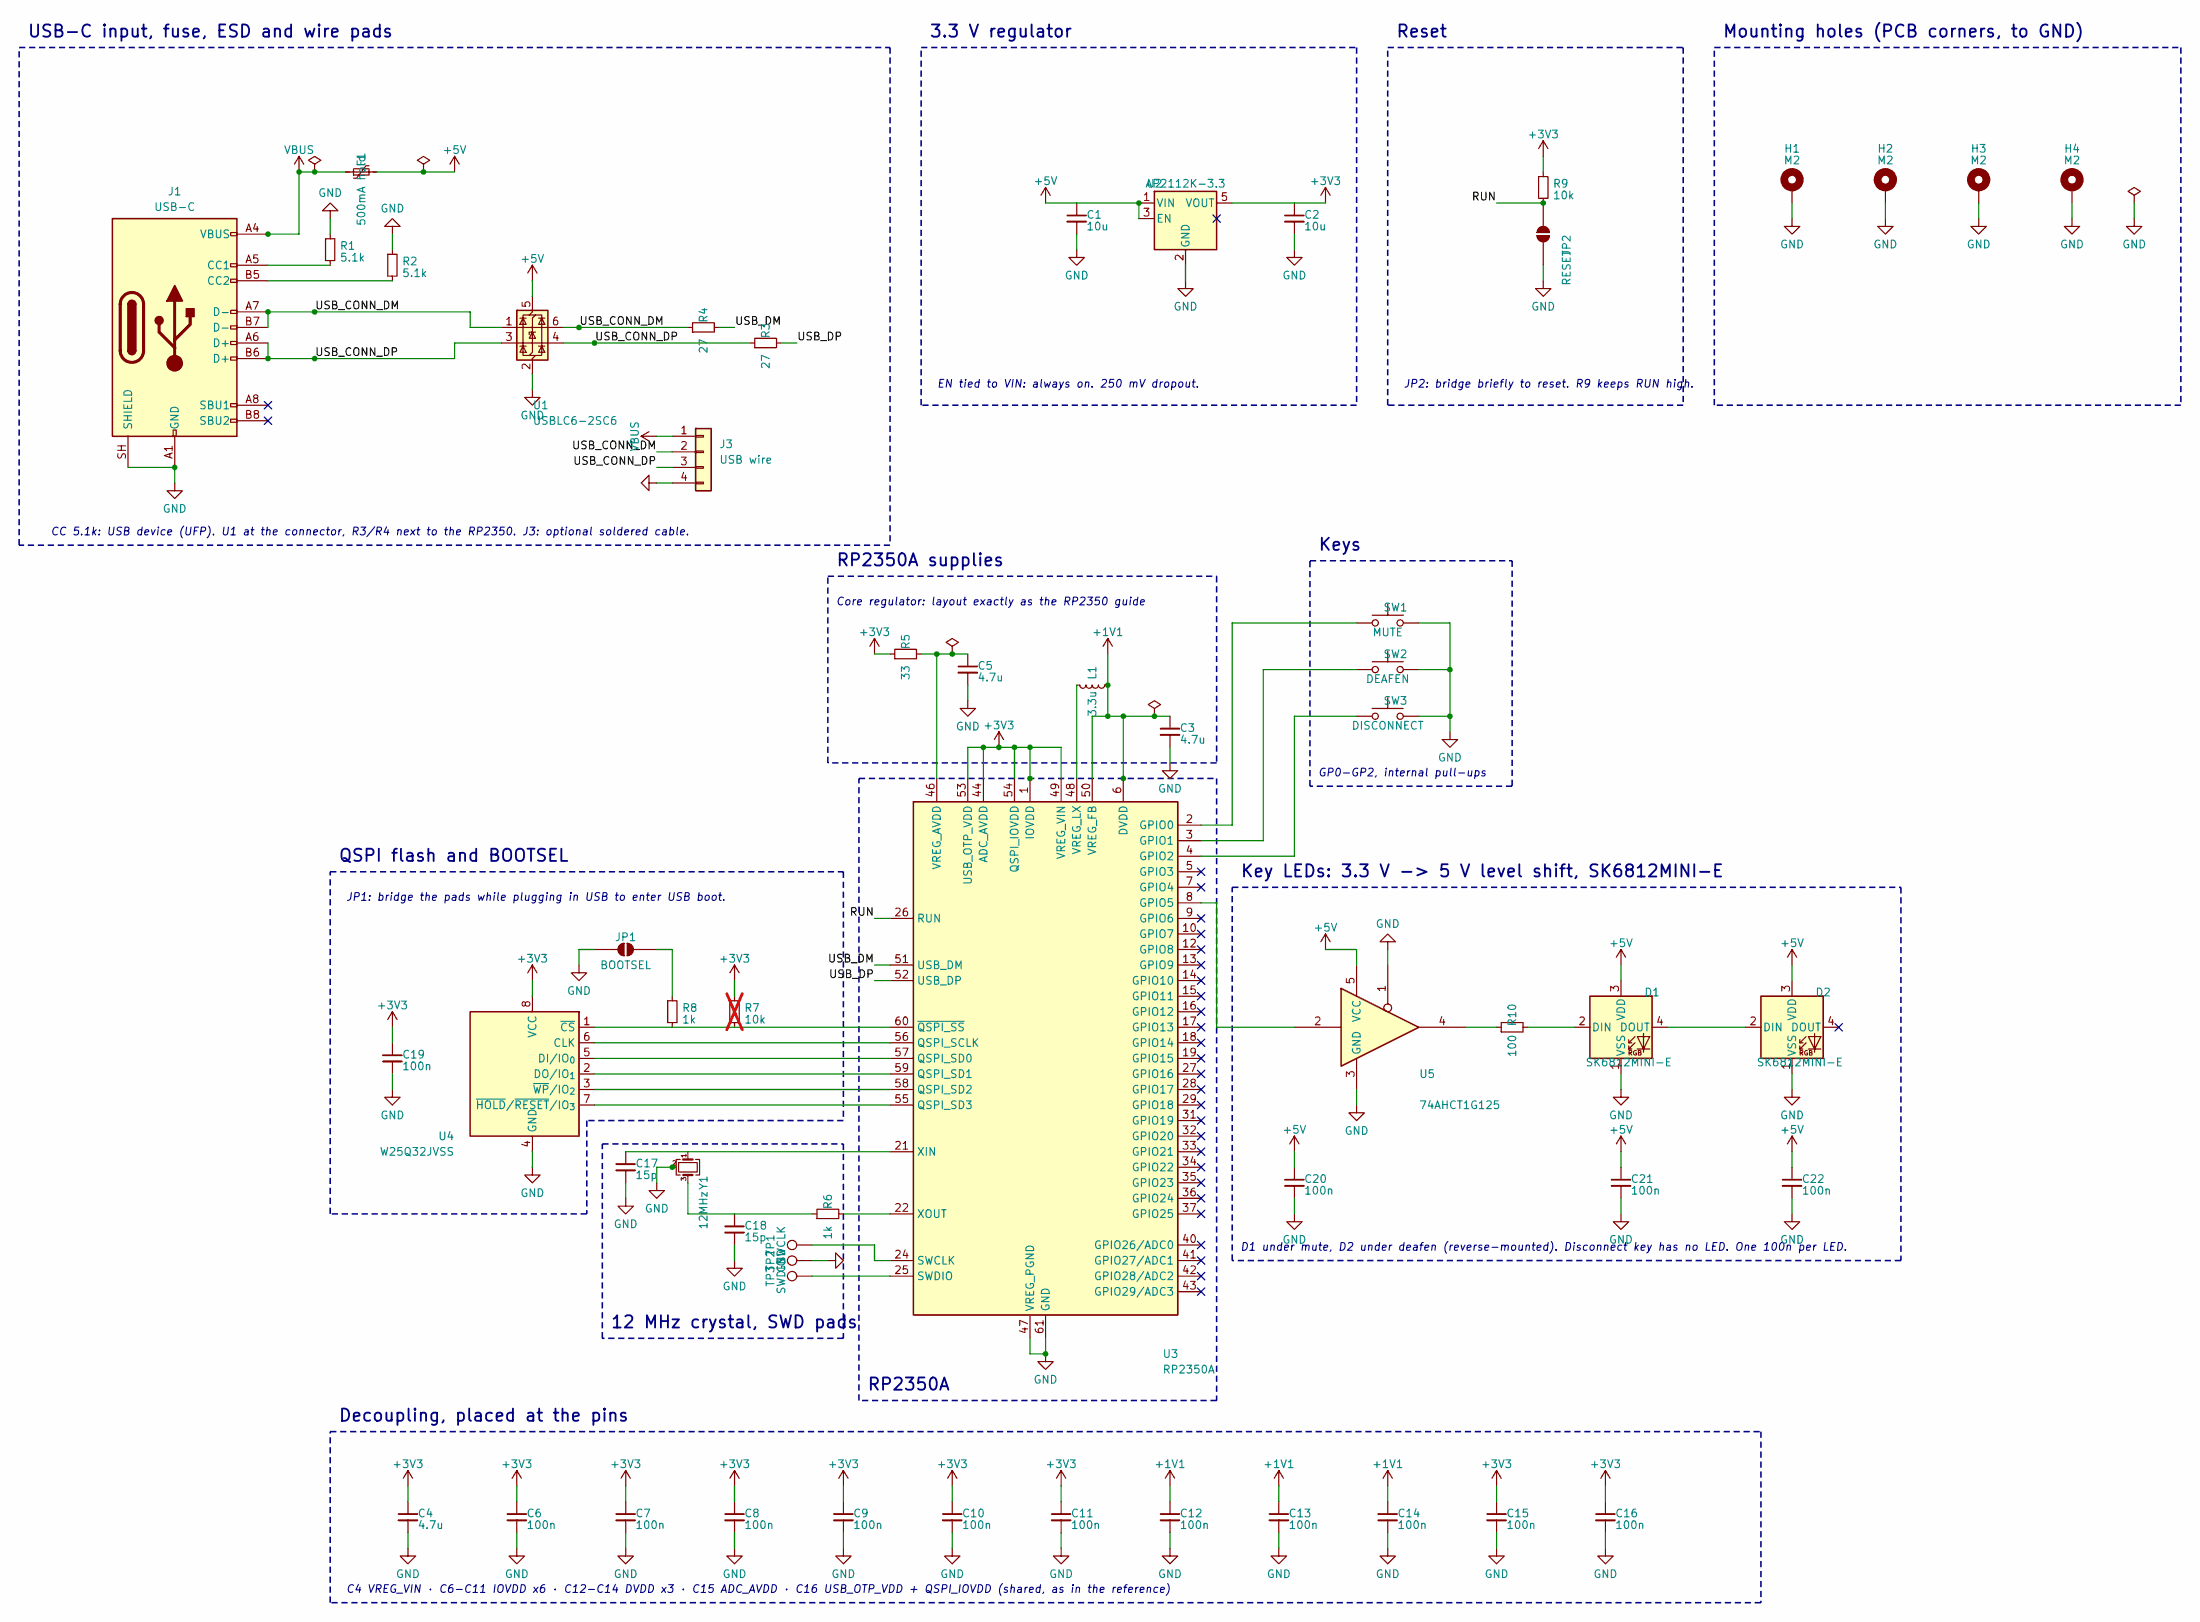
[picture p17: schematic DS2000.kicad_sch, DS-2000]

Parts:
C1, C2: 10u; C_0805_2012Metric; MPN CL21A106KAYNNNE; LCSC C15850
C3, C4: 4.7u; C_0402_1005Metric_Wide; MPN GRM155R60J475ME47D; LCSC C82453
C5: 4.7u; C_0402_1005Metric; MPN GRM155R60J475ME47D; LCSC C82453
C6, C7, C8, C9, C10, C11, C12, C13, C14, C15, C16, C19, C20, C21, C22: 100n; C_0402_1005Metric; MPN CL05B104KO5NNNC; LCSC C1525
C17, C18: 15p; C_0402_1005Metric; MPN 0402CG150J500NT; LCSC C1548
D1, D2: SK6812MINI-E; LED_SK6812MINI-E_3.2x2.8mm_P1.5mm_ReverseMount; MPN SK6812MINI-E; LCSC C5149201
F1: 500mA hold; Fuse_1206_3216Metric; MPN 1206L050/15YR; LCSC C151162
H1, H2, H3, H4: M2; MountingHole_2.2mm_M2_Pad_Via
J1: USB-C; USB_C_Receptacle_HRO_TYPE-C-31-M-12; MPN TYPE-C-31-M-12; LCSC C165948
J3: USB wire; PinHeader_1x04_P2.54mm_Vertical
JP1: BOOTSEL; SolderJumper-2_P1.3mm_Open_RoundedPad1.0x1.5mm
JP2: RESET; SolderJumper-2_P1.3mm_Open_RoundedPad1.0x1.5mm
L1: 3.3u; L_Abracon_AOTA-B201610S3R3-101-T; MPN AOTA-B201610S3R3-101-T; LCSC C42411119
R1, R2: 5.1k; R_0402_1005Metric; MPN 0402WGF5101TCE; LCSC C25905
R3, R4: 27; R_0402_1005Metric; MPN RC0402FR-0727RL; LCSC C138021
R5: 33; R_0402_1005Metric; MPN RC0402FR-0733RL; LCSC C138002
R6, R8: 1k; R_0402_1005Metric; MPN 0402WGF1001TCE; LCSC C11702
R7: 10k; R_0402_1005Metric; MPN 0402WGF1002TCE; LCSC C25744; not fitted
R9: 10k; R_0402_1005Metric; MPN 0402WGF1002TCE; LCSC C25744
R10: 100; R_0402_1005Metric; MPN 0402WGF1000TCE; LCSC C25076
SW1: MUTE; SW_Kailh_Choc_V1_1.00u
SW2: DEAFEN; SW_Kailh_Choc_V1_1.00u
SW3: DISCONNECT; SW_Kailh_Choc_V1_1.00u
TP1: SWCLK; TestPoint_Pad_D1.5mm
TP2: GND; TestPoint_Pad_D1.5mm
TP3: SWDIO; TestPoint_Pad_D1.5mm
U1: USBLC6-2SC6; SOT-23-6; MPN USBLC6-2SC6; LCSC C7519
U2: AP2112K-3.3; SOT-23-5; MPN AP2112K-3.3TRG1; LCSC C51118
U3: RP2350A; QFN-60-1EP_7x7mm_P0.4mm_EP3.4x3.4mm_ThermalVias; MPN RP2350A; LCSC C42411118
U4: W25Q32JVSS; SOIC-8_5.3x5.3mm_P1.27mm; MPN W25Q32JVSSIQ; LCSC C179173
U5: 74AHCT1G125; SOT-353_SC-70-5; MPN 74AHCT1G125GW,125; LCSC C12495
Y1: 12MHz; Crystal_SMD_3225-4Pin_3.2x2.5mm; MPN ABM8-272-T3; LCSC C20625731

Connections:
+1V1: C3.1, C12.1, C13.1, C14.1, L1.1, U3.6 (DVDD), U3.23 (DVDD), U3.39 (DVDD), U3.50 (VREG_FB)
+3V3: C2.1, C4.1, C6.1, C7.1, C8.1, C9.1, C10.1, C11.1, C15.1, C16.1, C19.1, R5.1, R7.1, R9.1, U2.5 (VOUT), U3.1 (IOVDD), U3.11 (IOVDD), U3.20 (IOVDD), U3.30 (IOVDD), U3.38 (IOVDD), U3.44 (ADC_AVDD), U3.45 (IOVDD), U3.49 (VREG_VIN), U3.53 (USB_OTP_VDD), U3.54 (QSPI_IOVDD), U4.8 (VCC)
+5V: C1.1, C20.1, C21.1, C22.1, D1.3 (VDD), D2.3 (VDD), F1.2, U1.5 (VBUS), U2.1 (VIN), U2.3 (EN), U5.5 (VCC)
/RUN: JP2.1 (A), R9.2, U3.26 (RUN)
/USB_CONN_DM: J1.A7 (D-), J1.B7 (D-), J3.2, R4.1, U1.1 (I/O1), U1.6 (I/O1)
/USB_CONN_DP: J1.A6 (D+), J1.B6 (D+), J3.3, R3.1, U1.3 (I/O2), U1.4 (I/O2)
/USB_DM: R4.2, U3.51 (USB_DM)
/USB_DP: R3.2, U3.52 (USB_DP)
GND: C1.2, C2.2, C3.2, C4.2, C5.2, C6.2, C7.2, C8.2, C9.2, C10.2, C11.2, C12.2, C13.2, C14.2, C15.2, C16.2, C17.2, C18.2, C19.2, C20.2, C21.2, C22.2, D1.1 (VSS), D2.1 (VSS), H1.1, H2.1, H3.1, H4.1, J1.A1 (GND), J1.A12 (GND), J1.B1 (GND), J1.B12 (GND), J1.SH (SHIELD), J3.4, JP1.1 (A), JP2.2 (B), R1.1, R2.1, SW1.2, SW2.2, SW3.2, TP2.1, U1.2 (GND), U2.2 (GND), U3.47 (VREG_PGND), U3.61 (GND), U4.4 (GND), U5.1, U5.3 (GND), Y1.2 (G), Y1.4 (G)
unnamed: C18.1, R6.1, Y1.3
unnamed: D1.2 (DIN), R10.2
unnamed: D1.4 (DOUT), D2.2 (DIN)
unnamed: J1.A5 (CC1), R1.2
unnamed: J1.B5 (CC2), R2.2
unnamed: JP1.2 (B), R8.1
unnamed: R10.1, U5.4
unnamed: SW1.1, U3.2 (GPIO0)
unnamed: SW2.1, U3.3 (GPIO1)
unnamed: SW3.1, U3.4 (GPIO2)
unnamed: U3.8 (GPIO5), U5.2
unnamed: U3.56 (QSPI_SCLK), U4.6 (CLK)
unnamed: U3.57 (QSPI_SD0), U4.5 (DI/IO_{0})
unnamed: U3.59 (QSPI_SD1), U4.2 (DO/IO_{1})
unnamed: U3.58 (QSPI_SD2), U4.3 (~WP/IO_{2})
unnamed: U3.55 (QSPI_SD3), U4.7 (~HOLD/~RESET/IO_{3})
unnamed: TP1.1, U3.24 (SWCLK)
unnamed: TP3.1, U3.25 (SWDIO)
unnamed: C5.1, R5.2, U3.46 (VREG_AVDD)
unnamed: L1.2, U3.48 (VREG_LX)
unnamed: C17.1, U3.21 (XIN), Y1.1
unnamed: R6.2, U3.22 (XOUT)
unnamed: R7.2, R8.2, U3.60 (~QSPI_SS), U4.1 (~CS)
VBUS: F1.1, J1.A4 (VBUS), J1.A9 (VBUS), J1.B4 (VBUS), J1.B9 (VBUS), J3.1

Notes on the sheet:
C4 VREG_VIN · C6-C11 IOVDD x6 · C12-C14 DVDD x3 · C15 ADC_AVDD · C16 USB_OTP_VDD + QSPI_IOVDD (shared, as in the reference)
3.3 V regulator
CC 5.1k: USB device (UFP). U1 at the connector, R3/R4 next to the RP2350. J3: optional soldered cable.
Keys
RP2350A
Reset
RP2350A supplies
D1 under mute, D2 under deafen (reverse-mounted). Disconnect key has no LED. One 100n per LED.
12 MHz crystal, SWD pads
GP0-GP2, internal pull-ups
QSPI flash and BOOTSEL
Decoupling, placed at the pins
Core regulator: layout exactly as the RP2350 guide
Mounting holes (PCB corners, to GND)
JP1: bridge the pads while plugging in USB to enter USB boot.
JP2: bridge briefly to reset. R9 keeps RUN high.
Key LEDs: 3.3 V -> 5 V level shift, SK6812MINI-E
EN tied to VIN: always on. 250 mV dropout.
USB-C input, fuse, ESD and wire pads

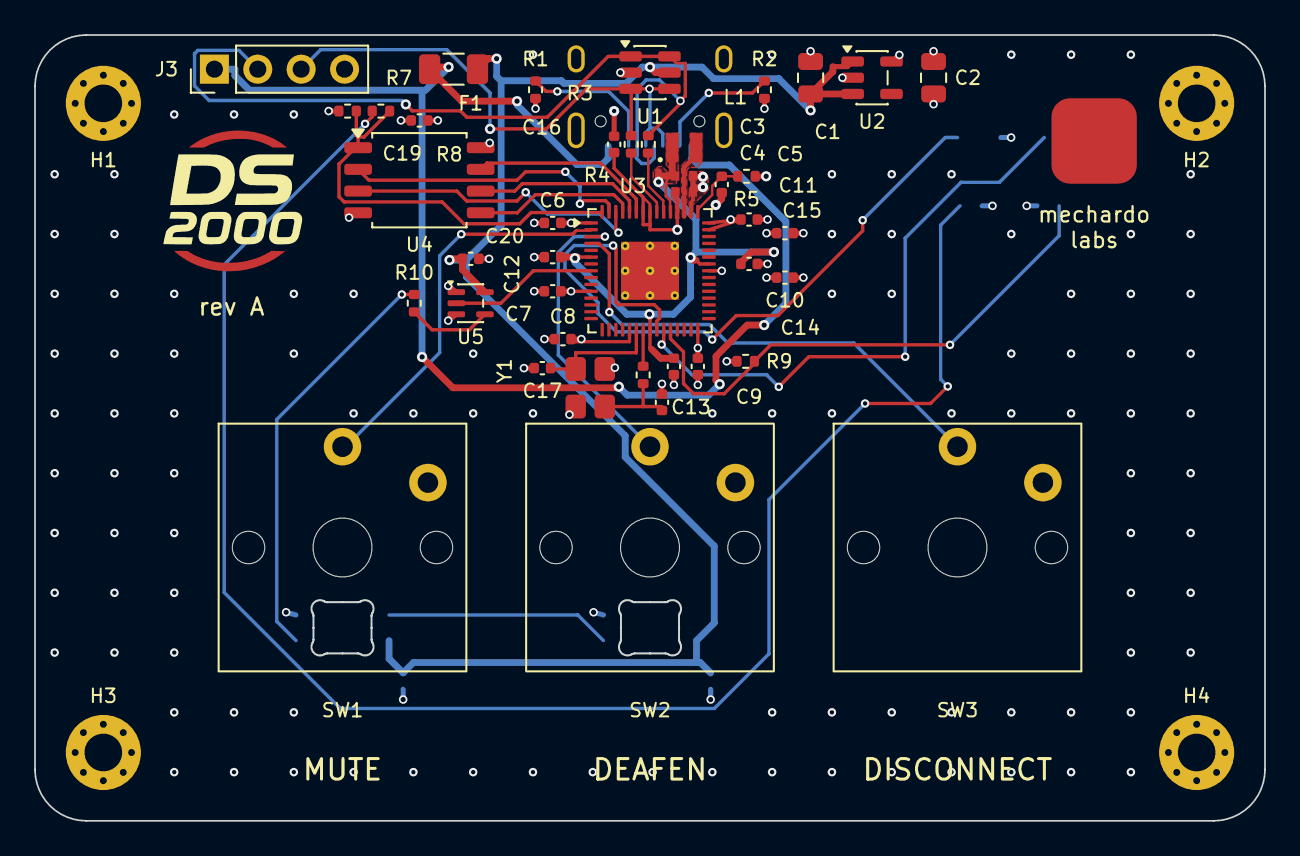
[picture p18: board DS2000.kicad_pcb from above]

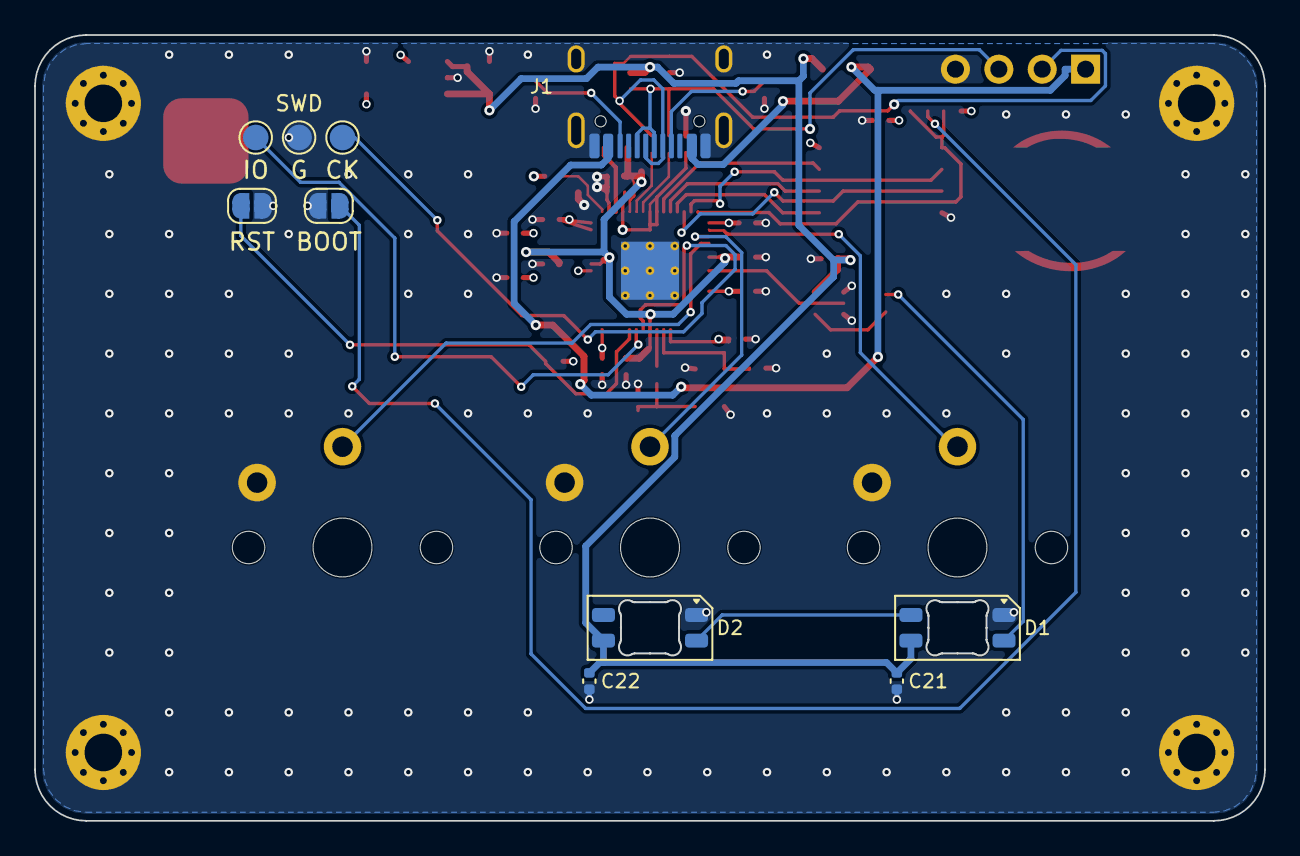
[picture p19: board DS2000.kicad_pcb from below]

Board: 4 copper layers, 72.0 x 46.0 mm, 58 parts (10 on the bottom side), 33 nets.

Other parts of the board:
LOGO1: Logo_Mechardo_5mm
LOGO2: Logo_DS2000_8.6mm

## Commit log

2025-08-14 init pcb
    [DS2000.kicad_pcb]
2025-08-14 more cahnges
    [DS2000.kicad_sch]
2026-09-28 feat: redraw the schematic around the RP2350A
    Rev A starts from a clean KiCad 10 project instead of patching the 2025 RP2040 draft, which is
    kept in history at 7db9552.
    - RP2350A with the on-chip switching regulator, decoupling, crystal, flash, BOOTSEL and RUN taken
    from Raspberry Pi's "Hardware design with RP2350" minimal design
    - USB-C with CC resistors, a series PTC and USBLC6 ESD, AP2112K 3.3 V LDO
    - Keys on GP0-GP2 to match the firmware's pins.h
    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
    [DS2000.kicad_pcb, DS2000.kicad_sch]
2026-09-28 ci: run KiBot on pull requests and main
    Adds ERC/DRC reports, schematic PDF, netlist, BOM, iBOM and visual
    schematic/layout diffs against the base of each change, uploaded as a
    workflow artifact. Violations are reported but do not fail the job yet.
    Refs #14
2026-09-28 feat: draw each stage in its own wired block and add USB wire pads
    The schematic is now laid out by stage (USB input, 3.3 V regulator, reset, mounting holes, RP2350A
    supplies, RP2350A, flash and BOOTSEL, crystal and SWD, keys, key LEDs, decoupling), each in a
    titled box and wired internally. Net labels remain only where a signal leaves its stage. The flash
    is mirrored so the six QSPI lines run straight into the RP2350A, and the core regulator is wired
    directly onto the MCU's supply pins.
    J3 adds four bare 2.54 mm holes (VBUS, D-, D+, GND) for soldering a USB cable instead of fitting
    the receptacle. They sit upstream of the fuse and the ESD, so a hard-wired cable is protected the
    same way.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
    [DS2000.kicad_sch]
2026-09-28 feat: drop the LED under the disconnect key
    Only mute and deafen carry state, so only they get an SK6812MINI-E. The chain is now U5 -> R10 ->
    D1 (mute) -> D2 (deafen), which maps one-to-one onto the two colours the RGB message already
    carries. D3 and its decoupling cap C23 are removed; ERC and the netlist check pass.
    [DS2000.kicad_sch]
2026-09-28 feat: replace the BOOTSEL button with a pair of bridgeable pads
    BOOTSEL is only needed to recover a board whose firmware no longer enumerates, so a tactile switch
    on the visible face is not worth its place. JP1 is an open solder jumper: bridging its two pads
    with tweezers while plugging in USB pulls QSPI_SS low through R8 and the RP2350A starts in USB boot
    mode. Not in the BOM. ERC and the netlist check pass.
    [DS2000.kicad_sch]
2026-09-28 feat: replace the RESET button with bridgeable pads
    Like BOOTSEL, reset is a recovery tool rather than something used day to day: unplugging USB resets
    the board, and firmware updates reboot into USB boot from software (DS-2000-Firmware#14, #15;
    DS-2000#35). JP2 is an open solder jumper from RUN to GND, bridged briefly to reset; R9 keeps RUN
    high. The visible face now has no tactile switches. ERC and the netlist check pass.
    [DS2000.kicad_sch]
2026-09-28 feat: start the rev A board with its mechanical layout fixed
    tools/pcb-generator/gen_pcb.py builds the board from the schematic's netlist, so footprints, nets,
    fields and symbol links match and DRC's schematic-parity check is clean. Update PCB from Schematic
    reports no changes.
    Fixed: a 72 x 50 mm outline with 3 mm corners, four M2 holes 4 mm in from the edges, the three keys
    in a row at 19.05 mm, the two SK6812MINI-E under the mute and deafen switches' LED windows on the
    bottom, and USB-C, SWD and the USB wire holes along the back edge. Everything else has a starting
    position in the strip behind the keys, grouped around the RP2350A, and is meant to be moved.
    Stackup is JLCPCB's JLC04161H-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
    [DS2000.kicad_pcb, DS2000.kicad_sch]
2026-09-28 feat: move USB-C underneath and add the missing 3D models
    The receptacle moves to the bottom side, still centred on the back edge with its face flush and
    opening backwards. The plug and cable now sit low, level with the tray, and the top strip loses
    the connector. Its GND pins join the bottom pour solidly: they are too narrow and close together
    for thermal spokes.
    KiCad's 3D library has no model for the MX switch, the HRO TYPE-C-31-M-12 or the QFN-60 the
    footprints point at. tools/3d-models/gen_models.py builds simplified STEP models from datasheet
    dimensions (switch with a 1u keycap, receptacle, RP2350A package) into 3dmodels/DS2000.3dshapes,
    referenced via ${KIPRJMOD} so they ship with th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
    [DS2000.kicad_pcb]
2026-09-28 feat: route rev A, shrink the board and move debug underneath
    The board is now fully routed: DRC reports no unconnected pads, no clearance or edge errors and
    full schematic parity. Only footprint silkscreen overlaps remain.
    - 72 x 46 mm, 4 mm shallower: with the USB-C underneath and the SWD connector gone, the strip
    behind the keys needed less depth
    - USB-C face now 1.2 mm past the back edge; its front shield tabs keep 0.6 mm of board
    - SWD is three bare pads instead of the JST connector, and every debug pad (SWD, BOOT, RST) sits on
    the bottom with its own label
    - top-side parts rearranged around the RP2350A pins they serve; decoupling caps in line with their
    pins, USB series resistor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
    [DS2000.kicad_pcb, DS2000.kicad_sch]
2026-09-28 feat: clean up the silkscreen and add the Mechardo Labs mark
    Reference designators ran off the board and piled up on each other across the visible face. They
    are now hidden (still in the file for assembly drawings), and the USB-C footprint's outline, which
    fell past the back edge, moves to the fab layer. The face keeps only the key legends, the debug
    labels underneath and the branding. DRC's silkscreen warnings are gone.
    The branding sits in the back-left corner, the one area of the face with no top copper:
    "DS2000" (no hyphen), "mechardo labs", "rev A", and the Mechardo Labs mark from mechardo3d.xyz.
    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
    [DS2000.kicad_pcb]
2026-09-28 feat: top ground pour, tidy references, site typography and a clean logo
    - F.Cu gets a GND pour too, so every layer is ground or +3V3 wherever there is no track. Its
    thermals may resolve to one spoke (DS2000.kicad_dru): each top GND pad already has its own via.
    - References are visible again, each placed by branding.py at the first spot beside its part that
    clears pads, holes, vias, other text and the board edge. 48 of 51 fit; C6, C11 and R3, in the
    tightest spot around the RP2350A, stay hidden.
    - Typography from mechardo3d.xyz instead of KiCad's stroke font: Sora for "DS2000" and "mechardo
    labs", IBM Plex Mono for legends, references and debug labels. The fonts are embedded in the b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
    [DS2000.kicad_pcb]
2026-09-28 feat: put the DS2000 logo on the board face
    The product logo from mechardo3d.xyz is traced into DS2000.pretty/Logo_DS2000_8.6mm by
    tools/logo/gen_ds2000_logo.py: its white lettering becomes silkscreen and its blue arcs ENIG gold,
    the board having no blue. The counters of D and 0 are real holes, joined to their outlines by
    keyhole cuts since footprint polygons cannot carry holes.
    The face now has two blocks in the only two areas without top copper: the DS2000 logo with
    "rev A" back-left, and the Mechardo Labs mark (now 5 mm) with "mechardo / labs" back-right. The
    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
    [DS2000.kicad_pcb]
2026-09-28 fix: shorten the crystal and flash clock routing, stitch the ground pours
    A full review (every net against Raspberry Pi's RP2350 minimal design, every footprint's pinout
    against its datasheet) found no wrong connection. It did find routing the autorouter had done
    poorly:
    - XIN ran 14 mm with two vias. preroute.py now hand-routes the crystal loop as locked tracks with
    the crystal turned under XIN/XOUT so the nets never cross: XIN 7.4 mm, XOUT 2.1 mm, the crystal
    output 4.9 mm, all on F.Cu with no vias. IOVDD pin 20, beside XIN, runs to C8 above it.
    - The QSPI clock ran 35.5 mm with four vias. R7, R8 and C16 move out of the corridor between the
    flash and the RP2350; SCLK is now 11 mm wi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
    [DS2000.kicad_pcb]
2026-09-28 chore: fill the copper zones
    Zones filled in KiCad (B), so the committed board carries its pours. No footprint, track or via
    changed.
    [DS2000.kicad_pcb]
2026-09-28 fix: drop the fill attribute from the schematic's block outlines
    KiBot's schematic parser rejects a polyline carrying (fill); KiCad treats it as the default
    anyway. The eleven block outlines lose it, here and in the generator. Geometry and UUIDs are
    unchanged, so board parity holds.
    [DS2000.kicad_sch]
2026-09-28 feat: switch to Kailh Choc V1 low-profile keys
    - SW_Kailh_Choc_V1_1.00u footprint in the project library, generated from Kailh's CPG1350
    drawing (geometry matches kiswitch, MIT); courtyard on the 13.8 mm lower housing
    - own STEP models for the Choc V1 switch and an MBK-style keycap
    - 18 mm key pitch, key row 1 mm forward, LEDs 4.7 mm south of each switch centre
    - board re-placed and re-routed with the pipeline; ERC/parity clean, DRC only the known
    text_thickness and lib_footprint_mismatch warnings
    [DS2000.kicad_pcb, DS2000.kicad_sch]
2026-09-28 docs: README gallery with the bare layout, underside, back view and schematic
2026-09-28 docs: README with the board in its enclosure, exploded view and close-ups
2026-09-28 fix: copy the RP2350A minimal design's core regulator layout
    Raspberry Pi says the regulator layout should be copied, not improvised: the inductor's field upsets
    the output capacitor when placed or oriented differently. The autorouted rev A had L1 4.6 mm away
    on a 0.2 mm VREG_LX track, the output cap past the inductor and VREG_AVDD running under it.
    - L1, C3, C4, C5 and C16 at the reference's offsets from VREG_LX (pin 48), from their KiCad files
    (RPI-RP2350A-MINIMAL R4-S1, MIT); hand routing in preroute.py, their four small pours in
    vreg_pours.py
    - L1 footprint for the Abracon AOTA-B201610S3R3-101-T with its polarity dot; the schematic symbol
    turned so pin 1 (the dot) is +1V1, as in t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
    [DS2000.kicad_pcb, DS2000.kicad_sch]
2026-09-28 feat: switch references in a row under the keys
    SW1-SW3 were placed by the reference placer wherever it found room (two above their key, one below).
    branding.py now pins them centred under each keycap, between its front edge and the key legend, so
    they read from the front in line with MUTE / DEAFEN / DISCONNECT.
    [DS2000.kicad_pcb]
2026-09-29 feat: keep autorouted tracks off the visible top face
    The board is the product's top face, but Freerouting used F.Cu freely: +5V to the LEDs, the debug
    lines, RUN and the key lines ran across the key area and beside the logos. top_keepout.py now puts a
    track keepout on F.Cu over everything but the component strip around the RP2350A while the
    autorouter runs, and takes it out afterwards, so every longer run goes on B.Cu.
    F.Cu tracks: 399 -> 344 mm, all inside the strip; the key area and the sides carry none. XIN, QSPI
    SCLK, VREG_LX and USB D+/D- between U3 and R3/R4 are unchanged.
    [DS2000.kicad_pcb]
2026-09-29 feat: BOM with LCSC numbers and JLCPCB fabrication outputs in CI
    - tools/bom/set_fields.py: the parts table for assembly (MPN, manufacturer, LCSC), each number
    checked on its LCSC/JLCPCB page or taken from the RP2350A minimal design's BOM; writes the fields
    into the schematic and onto the board's footprints (schematic parity stays clean)
    - F1 is now the 15 V 1206L050/15YR (same 500 mA hold), for margin on VBUS
    - kibot/fab.kibot.yaml: KiBot's JLCPCB template (gerbers, drill, BOM, CPL with rotation fixes,
    zip) and the board's STEP with its origin at the board centre (grid origin set to 100, 94)
    - CI builds them on every change; DRC and parity now fail the job on any new error
    - design do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
    [DS2000.kicad_pcb, DS2000.kicad_sch]
2026-10-08 feat: cost-down for one-sided JLC assembly
    Move every assembled part to the top side so JLC can assemble the board
    with Economic PCBA, and swap parts that have a JLC basic (no feeder fee)
    or cheaper drop-in equivalent.
    - remove the USB-C receptacle (J1) and its CC resistors (R1, R2): the USB
    cable is soldered to J3, which now feeds +5V directly
    - remove the PTC fuse (F1): the host port limits the current
    - D1/D2: SK6812MINI-E reverse-mount (bottom) -> WS2812B-2020-V6 on the
    top, inside the Choc V1 LED window; no more board cut-outs
    - C21/C22 move to the top, between the keys, under the keycap overhang
    - U2: AP2112K-3.3 (SOT-23-5) -> XC6206P332MR (SOT-23-3, basic)
    - Y1: ABM8-272-T3 -> YX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
    [DS2000.kicad_pcb, DS2000.kicad_sch]
2026-10-08 fix: U4 value matches the 2 MB flash
    [DS2000.kicad_pcb, DS2000.kicad_sch]
2026-10-16 fix: keep the USB-C footprint, hand-soldered instead of assembled
    The cost-down removed J1 to keep JLC's assembly one-sided. The receptacle
    only has to stay out of JLC's files for that, not off the board: J1 is back
    in its place on the bottom, marked DNP and excluded from the BOM and the
    placement file, to be soldered by hand after assembly. J3 stays as the
    alternative for a soldered cable.
    - J1's VBUS goes straight to +5V, like J3; there is still no fuse.
    - R1/R2, the 5.1k CC pull-downs a USB-C host needs before it supplies 5 V,
    are back on the top side (basic part, assembled).
    - J1's escape routing is main's; the +5V and D+ runs it displaced were
    rerouted around it.
    - set_fields.py, R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
2026-10-16 fix: write the schematic in the format KiBot reads
    The previous commit resaved the whole schematic with kicad-cli, which adds a
    fill to every polyline; KiBot's parser rejects that. This keeps the committed
    text and only adds or moves the blocks for J1, R1, R2 and J3.
2026-10-16 fix: back to the reference crystal, ABM8-272-T3 with 15 pF
    JLC's design review flagged the basic YXC crystal against Raspberry Pi's
    RP2350 hardware design guide. A crystal that does not start costs a whole
    batch, against one extended-part fee: Y1 is the Abracon ABM8-272-T3 again
    (C20625731, Economic PCBA) with 15 pF load caps (C1548), as the reference.
2026-10-16 fix: SK6805-EC20 key LEDs, which JLC assembles in Economic PCBA
    JLC's order review reported the WS2812B-2020 (C52917434) as Standard-PCBA
    only, which brings back the setup fee and a 70 mm minimum board side. The
    OPSCO SK6805-EC20 (C2890036) is the same 2.0 x 2.0 mm top-emitting,
    WS2812-compatible part (800 kHz, GRB), assembles in Economic, and is
    thinner: 0.65 mm instead of 0.84, more room under the Choc V1 housing.
    - Its pinout (1 VDD, 2 DOUT, 3 GND, 4 DIN) is not in KiCad's library, so
    the project gets its own symbol library (DS2000.kicad_sym, sym-lib-table)
    and footprint (datasheet land pattern: 0.8 x 0.7 mm pads), plus a STEP
    model from gen_models.py.
    - Turned 270 deg, every net k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
2026-10-23 feat: production review changes to the board and schematic
    - U4: 4 MB flash (W25Q32JVSSIQ, C82344), the RP2350-Zero's size, room for
    A/B firmware updates
    - C1/C2: 10u -> 4.7u (CL21A475KAQNNNE, C1779, basic), so VBUS stays near
    USB 2.0's 10 uF
    - J1 is no longer DNP: a `Config` field (+standard) lets the KiBot variant
    decide whether JLC fits it (standard) or it is soldered by hand (economic)
    - J3: four SMD wire pads on the bottom beside J1 (WirePads_1x04_P2.54mm_SMD)
    instead of through holes on the visible face; its USB branch drops from
    ~20 mm to ~12 mm per line
    - USB pair from J3 to U1 hand-routed as a coupled pair, 0.25 mm / 0.15 mm
    (~90 ohm on JLC04161H-7628); USB net class upd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
2026-10-23 fix: keep the panel's silkscreen references as designed, number copies in the CPL
    KiKit's renamed references (C1_0 ...) were printed on the visible face. The
    panel now keeps them as on the single board; panel_bom.py numbers the copies
    in the placement file and the BOM that JLC gets.
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2026-10-23 fix: keep the test pads' labels clear of their symbols, correct the stage note
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2026-10-25 fix: redraw the moved switch-area tracks as straight 45-degree runs
2026-10-29 fix: redraw the long runs as straight lines and 45-degree corners
    - +5V: J3 pin 1 drops into one 45-degree line that continues as the
    left side of the ring; under the LEDs the ring is one straight bus on
    B.Cu, and the +5V run that crossed the face under SW2 moves to the back.
    - LED row: DIN, DOUT and GND vias level with their pads; D1 -> D2 data
    runs straight beside the bus.
    - BOOTSEL: 63 -> 55 mm, no odd angles, beside SWDIO into JP1.
    - MX pin 1 -> Choc pin 1: a 45 and a straight run instead of 18 degrees.
    DRC unchanged (0 errors, 0 unconnected); every new segment was checked
    for 0.2 mm clearance before it was written.
2026-10-29 fix: draw the GPIO5 wire to U5 clear of the stage frames
    Its vertical run sat on the MCU stage's dashed border, so the line
    from U3 pin 8 seemed to stop there. It now crosses both borders and
    drops inside the Key LEDs box. Same netlist, ERC 0.
2026-10-29 fix: take the vias out of the SMD pads
    Fifteen vias overlapped the pad they served: Y1, U1, U2, U4, U5, C1,
    C2, JP1, JP2 and TP2. On the reflowed parts the open via would wick
    solder from the joint. Each is now a dogbone: a straight or 45-degree
    stub from the pad centre to a via 0.12 mm clear of the pad.
    To make room, BOOTSEL's first via and vertical move 0.76 mm right, and
    R10 -> U5 pin 4 drops 0.35 mm.
    J3's two USB vias stay in their wire pads: those are hand-soldered,
    and moving the vias would lengthen the USB pair.
    DRC unchanged (0 errors, 0 unconnected).
2026-10-29 fix: keep the C1, C2 and U2 dogbone vias off the board edge
    The previous commit put these three vias 0.43-0.65 mm from the back
    edge, past the pours' 0.5 mm margin. They now sit beside their pads,
    1.3 mm from the edge; no via ring is closer than 0.9 mm, as with the
    stitching grid. DRC unchanged.
2026-10-29 fix: production audit findings before ordering
    - SK6805-EC20 (D1/D2): pins renumbered to the datasheet LCSC serves now
    (SK6805-EC20-001 Rev A1: 1 GND, 2 DIN, 3 VDD, 4 DOUT), pin-1 chamfer
    on the GND corner. Copper unchanged; the old rev A2 numbering put our
    pin-1 mark on the corner opposite JLC's pin 1, inviting a 180 degree
    placement that reverse-powers the LED.
    - Silkscreen: references, "mechardo labs", SWD and JLCJLCJLCJLC at
    1.0 mm, JLC's minimum height; at 0.8 mm the strokes measured ~0.14 mm,
    under the 0.153 mm minimum. Eight references in the RP2350A cluster
    no longer fit and stay hidden.
    - Logos' exposed copper re-tied to GND after re-running branding.py.
    - Y1's moved s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
2026-10-30 fix: isolate RP2350 regulator copper and ground return
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2026-10-30 fix: route USB through ESD pad junctions and add ground references
2026-10-30 fix: move J1 USB vias off U1's pad and away from the board edge
    #36 left J1's D+ via overlapping U1 pad 4 (via-in-pad on a reflowed part)
    and J1's D- via plus one GND stitching via 0.35 mm from the back edge,
    inside the 0.5 mm pour inset. DRC flags neither.
    - D+ and D- vias now sit between U1's pad columns, on the bridges that
    already join pads 3/4 and 1/6; R3/R4 still leave pads 4 and 6.
    - J1's D- escape turns into its via below the edge keepout.
    - VBUS via beside D- shrinks to the board's standard 0.5/0.25 mm.
    - The edge GND via is removed: no legal spot exists in the In2 island,
    which stays stitched through its other via.
    - TP5's +3V3 dogbone is redrawn at 45 degrees.
    - Schematic gen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
2026-11-01 refactor: center the GND stitching-via grid on the board
    The 3.5 mm stitching grid sat 1.6 mm left and 0.85 mm up from the board
    centre (1.15 mm edge margin on the left, 4.35 mm on the right). Translate
    it to be symmetric about (100, 94): x 66.75-133.25, y 73-115.
    Keep the existing pattern; drop the 9 positions that now collide with
    tracks or pads near U3 and the test points (102 -> 93 vias). Zones
    refilled. Routing vias and every other object are unchanged.
2026-11-01 fix: drill U1's thermal vias at 0.25 mm to stay in JLC's cheaper via class
    KiCad's QFN-60 ThermalVias footprint drills its nine 0.5 mm vias at 0.2 mm,
    the only 0.2 mm holes on the board. Ordering a 0.2 mm minimum via at JLCPCB
    adds the via surcharge plus a forced 4-wire Kelvin test and TG155 material,
    about $37 on five boards.
    - add DS2000:QFN-60-1EP_7x7mm_P0.4mm_EP3.4x3.4mm_ThermalVias_Drill0.25mm,
    the stock footprint with 0.25 mm drills (0.125 mm annular ring, like the
    other vias)
    - point U1 at it in the schematic and the board
    - raise the project's minimum through-hole diameter to 0.25 mm
    - document the via class in design-rev-a.md
2026-11-01 fix: drill every via at 0.3 mm to use JLC's standard via class
    0.25 mm is not JLC's standard class either: choosing 0.25mm/(0.35/0.4mm)
    still adds a via surcharge and forces the 4-wire Kelvin test and TG155,
    the same as 0.2 mm. Only 0.3mm/(0.4/0.45mm) is free.
    - all 124 board vias go from 0.25 to 0.3 mm drill (pads stay 0.5 mm,
    0.1 mm annular ring); the 63 vias already at 0.3 mm are unchanged
    - U1's local footprint becomes ..._ThermalVias_Drill0.3mm
    - project minimum through-hole and the Default net class via drill
    go to 0.3 mm
    - design-rev-a.md: order with 0.3mm/(0.4/0.45mm); before/after image
2026-11-01 fix: keep generators, 3D model and docs in line with 0.3 mm vias
    Review of the 0.3 mm via change:
    - pcb-generator (fanout, stitch, preroute, gen_pcb) and gen_sch still
    produced 0.25 mm vias and KiCad's stock QFN-60 footprint; a rerun of
    the pipeline would have brought them back
    - the local QFN-60 footprint now uses the project's STEP model, as the
    board already does, so updating the footprint from the library keeps
    the 3D model
    - the RP2350A is U3, not U1 (U1 is the USBLC6 ESD): fixed in
    design-rev-a.md and the before/after image; the two earlier commit
    messages of this branch say U1 by mistake
2026-11-01 fix: switch U4 and U5 to LCSC parts JLC has in stock
    JLC's BOM check for the standard order flagged two shortages:
    - U4 W25Q32JVSSIQ C82344: 0 in stock (pre-order only). The same Winbond
    part, SOIC-8 208 mil, is stocked as C179173.
    - U5 74AHCT1G125GW,125 C12495: 6 in stock, 9 needed. TI SN74AHCT1G125DCKR
    C350557 is the same function in SC-70-5 (SOT-353) with the same pinout
    (1 OE, 2 A, 3 GND, 4 Y, 5 VCC; TI SCLS378P table 4-1), AHCT TTL input
    (VIH 2 V), 4.5-5.5 V.
    Fields updated in the schematic, the board footprints (parity clean),
    tools/bom/set_fields.py, gen_sch.py and the BOM table in design-rev-a.md.
2026-11-01 fix: correct JLC placement rotation of U1, U3 and U5
    JLC's placement preview for the standard order showed three parts 90°
    off: the RP2350A (U3, QFN-60), the USBLC6 (U1, SOT-23-6) and the buffer
    (U5, SC-70-5). Their model's pin 1 sat at the top right with the leads
    across the footprint's pads, while the silkscreen and pad 1 are at the
    top left. KiBot's JLCPCB table gave 270, 180 and 180; rotating each part
    90° counter-clockwise in JLC's editor (to 0, 270 and 270) puts pin 1 on
    the silkscreen mark and the leads on the pads.
    KiBot's rot_footprint filter reads a `JLCPCB Rotation Offset` field and,
    when present, uses it instead of its table (final = footprint rotation +
    field). All three foot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
